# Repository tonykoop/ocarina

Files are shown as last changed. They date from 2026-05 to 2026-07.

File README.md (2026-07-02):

# Ocarina — Slip-Cast Ceramic Vessel-Flute Family

> *Engineering documentation for a 3D-printed-master, plaster-mold, cone-6-stoneware slip-cast ocarina family — from Helmholtz physics through the parametric design table to a V5 candidate build packet.*

**Status:** L2 V5 build-packet candidate

Current status: **V5 explorer/build-packet candidate, not build-ready**. The
repo has a parametric design table, OpenSCAD starter, SVG drawing previews, and
concept images, but the build-controlling values for chamber volume, voicing
geometry, clay shrinkage, and tuning still need physical measurement before
they can be treated as validated fabrication authority.

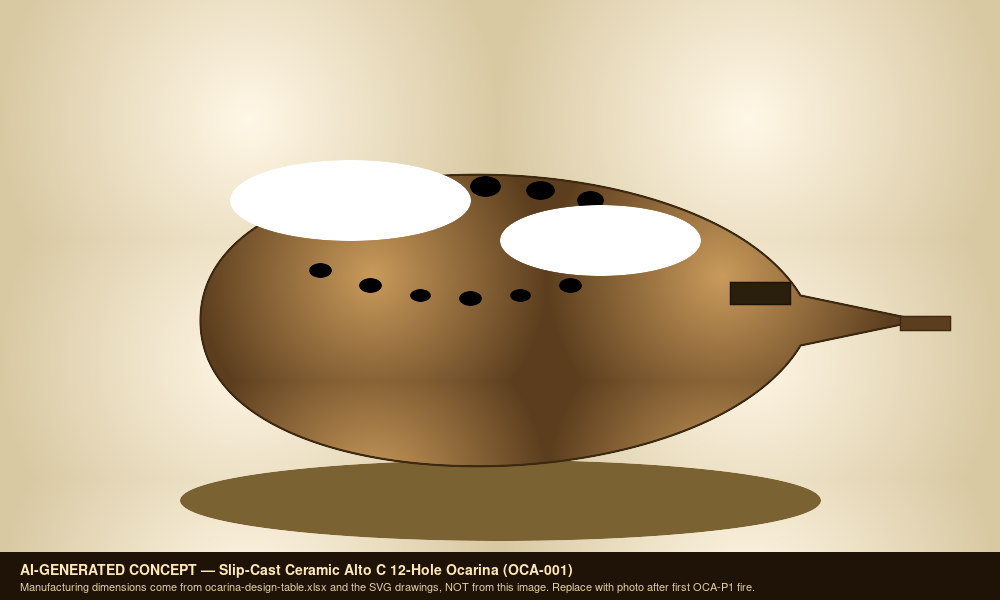
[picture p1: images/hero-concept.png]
Hero — AI-generated concept render of a slip-cast Alto C 12-hole ocarina (placeholder until first prototype is photographed)

*AI-generated concept render — replace with photo of first OCA-P1 prototype after firing. Manufacturing dimensions come from the parametric design table, not from this image.*

## What this is

Engineering documentation for a small family of slip-cast ceramic ocarinas, built around the Helmholtz vessel-resonator model and a 3D-printed-master / plaster-mold / Cone-6-stoneware production pipeline. The repository combines:

1. **A parametric design table** ([`ocarina-design-table.xlsx`](ocarina-design-table.xlsx)) — chamber volume, voicing-window geometry, wall thickness, shrinkage, and a 12-hole fingering chart with formula-driven hole-area / cumulative-area / frequency columns. Master scale factor `1/(1 - measured_shrinkage)` is parameterized; for a 12% shrinkage assumption, the master scales at ~1.136×.
2. **A full build packet** ([`design.md`](design.md), [`bom.csv`](bom.csv), [`sourcing.csv`](sourcing.csv), [`cut-list.csv`](cut-list.csv), [`validation.csv`](validation.csv), [`assembly-manual.md`](assembly-manual.md), [`supplier-rfq.md`](supplier-rfq.md), [`drawing-brief.md`](drawing-brief.md), [`visual-bom-brief.md`](visual-bom-brief.md), [`wolfram-starter.wl`](wolfram-starter.wl)) — the same scaffold used across the [`tonykoop`](https://github.com/tonykoop) musical-instrument catalogue.
3. **A capstone slide deck and printable shop packet** ([`capstone-deck.pptx`](capstone-deck.pptx), [`print-packet.pdf`](print-packet.pdf)) — recruiter-facing artifacts that show the design record, authority boundaries, and next validation gates.

Sister repos: [`gemshorn`](https://github.com/tonykoop/gemshorn) (where slip-cast horn-flute mold workflow was established and is the closest comparable build packet), [`transverse-flute`](https://github.com/tonykoop/transverse-flute) (slip-cast workflow at larger scale), [`flutes`](https://github.com/tonykoop/flutes) (the NAF / open-pipe family with empirical K2 bore corrections), and [`instrument-maker`](https://github.com/tonykoop/instrument-maker) (the agent skill that generated this packet).

## Background — what makes an ocarina different

The ocarina (Italian *little goose*) is a closed-cavity vessel flute. Unlike a transverse flute or a Native American style flute, **pitch is set by chamber volume and total open-hole area, not by tone-hole position along a bore**. The governing model is the Helmholtz resonator:

```
f = c/(2π) · √( A_open / (V_chamber · L_eff) )
```

where `A_open` is the cumulative open hole area, `V_chamber` is the closed cavity volume, and `L_eff = wall_thickness + 0.6·√(A_open/π)` is the effective neck length with a flanged-port end correction. The full physics treatment is in [`design.md`](design.md) (Governing Model section) and in [`wolfram-starter.wl`](wolfram-starter.wl).

The practical consequence is that ocarina hole positions are an **ergonomic** problem (where the fingers reach), not an acoustic one (where the standing wave wants the holes). This makes the ocarina an unusually clean parametric-design target — change the chamber volume, the whole register transposes; change the cumulative area, the fingering chart re-tunes — but it puts an unusually heavy burden on **fipple/voicing geometry**, which the Helmholtz model says nothing about and which has to be tuned empirically.

## V5 authority map

The current fabrication authority is limited to the design table and OpenSCAD
starter as **candidate geometry**, not validated production geometry:

- `ocarina-design-table.xlsx` carries the inferred workbook values for chamber
  volume, wall thickness, voicing-window size, shrinkage assumption, and hole
  schedule.
- `cad/ocarina_master.scad` is a parametric master-shape starter derived from
  those values. It does not validate the windway, labium, or final fired pitch.
- `family-spec.csv` records the vessel-flute scaling and authority status for
  chamber volume, voicing geometry, shrinkage, and tuning.
- `visual-output-register.csv` marks the CAD/design table as candidate
  fabrication authority and labels SVG/image outputs as previews or concepts.
- `cad/mcp-session-log.md` records that no MCP-generated V5 artifacts were
  created in this lane; future OpenSCAD/Blender/Illustrator/Photoshop sessions
  should append there.

## Family targets

The first prototype is the magazine-standard **Alto C 12-hole** (target low note A4 = 440 Hz, target high note F6 ≈ 1397 Hz, chamber volume 130 cm³ per the design table). The same parametric model can drive a Soprano C / Bass C extension once the Alto C voicing geometry is stable — see the prototype ladder in [`design.md`](design.md).

| Prototype | Goal | Success criteria |
|---|---|---|
| **OCA-P0** voicing tile | Fipple-only practice cavity | Clear tone on a disposable test cavity |
| **OCA-P1** closed vessel | Verify chamber volume + fipple | Stable A4-ish all-closed tone before holes |
| **OCA-P2** 4-hole | Prove tuning workflow | Four tuned notes within ±25 ¢ post-bisque |
| **OCA-P3** 12-hole | Full range | Chromatic A4–A5 playable, no blocked grip |
| **OCA-P4** matched set | Soprano / Alto / Bass C | Shared mold logic, shared glaze family |

## Hardware alignment — Bambu printer + ceramic kiln

This repo is one of the **slip-casting targets** for the in-flight Bambu printer + kiln pipeline. The build chain is:

1. Parametric design table sets fired-body dimensions.
2. Master scale factor `1/(1 - measured_shrinkage)` scales the master STL.
3. Bambu print masters in PLA (or sealable resin); sand layer lines and seal.
4. Two-piece plaster mother mold around the sealed master.
5. Slip-cast Cone 6 stoneware → demold leather-hard → cut voicing window and finger holes undersized → bisque → tune → glaze → final fire.
6. Validate against [`validation.csv`](validation.csv); fold corrections back into the design table.

The same pipeline serves the [`udu`](https://github.com/tonykoop/udu), [`gemshorn`](https://github.com/tonykoop/gemshorn), and [`transverse-flute`](https://github.com/tonykoop/transverse-flute) repos.

## Repository structure

```
ocarina/
├── README.md                       ← you are here
├── LICENSE                         ← CC-BY 4.0
│
├── design.md                       ← Helmholtz model, design intent, prototype ladder
├── ocarina-design-table.xlsx       ← parametric spreadsheet (formulas, blue inputs)
│
├── bom.csv                         ← bill of materials
├── sourcing.csv                    ← supplier/search tracker
├── cut-list.csv                    ← rough/finished dimensions, tolerances
├── validation.csv                  ← target/measured tuning + cents-error log
├── supplier-rfq.md                 ← RFQ template for slip / plaster / consumables
│
├── assembly-manual.md              ← shop-floor build sequence
├── drawing-brief.md                ← required views + critical dimensions for CAD
├── visual-bom-brief.md             ← visual-BOM art-direction brief
├── wolfram-starter.wl              ← Helmholtz physics starter notebook
│
├── capstone-deck.{md,pptx}         ← capstone slide deck (12 slides)
├── print-packet.{md,html,pdf}      ← combined print-ready shop packet (18 pp)
├── capstone-manifest.json          ← orientation manifest
│
├── cad/                            ← parametric body OpenSCAD starter
├── cnc/                            ← (deferred — slip-cast does not need CNC unless turning a wooden master)
├── drawings/                       ← SVG drawings: section, fipple detail, hole layout
├── images/                         ← AI-generated concept renders (placeholders)
└── evolution/                      ← Stage 0 evolution-pipeline intake (manifest, design-intent, revisions)
```

## Status

| Section | Status |
|---|---|
| Parametric design table + Helmholtz model | ✓ done |
| Build packet (BOM / sourcing / cut-list / validation / RFQ) | ✓ done |
| Assembly manual + drawing brief | ✓ done |
| Wolfram physics starter | ✓ done |
| Capstone deck + print packet | ✓ done (auto-generated, recruiter-facing) |
| Concept renders (AI-generated, captioned) | ✓ done (placeholders) |
| Parametric CAD (OpenSCAD starter) | candidate only (master-shape; voicing detail by hand) |
| Dimensioned drawings (SVG) | derived preview only until reviewed against CAD/design-table authority |
| V5 authority/register files | added: `family-spec.csv`, `visual-output-register.csv`, `validation-loop.csv`, `cad/mcp-session-log.md` |
| Production-ready CAD (.step / .stl) | **deferred** — generated after empirical voicing validation in build queue |
| Mold turning / CNC toolpaths | **deferred** — slip-cast workflow uses 3D-printed master, not turned wooden master |
| First OCA-P1 prototype build | forthcoming (Bambu + kiln pipeline) |

Tier 3 production files (.step, validated .stl, .dxf for laser, .gcode for CNC) are **out of scope until the first OCA-P1 prototype validates voicing geometry**. See the README's status table and [`design.md`](design.md) "Open Assumptions" for the deferral reasoning.

## License

Released under [CC-BY 4.0](LICENSE) — original written content, design files, photographs, and physics work in this repository are mine, free to reuse and adapt with credit.

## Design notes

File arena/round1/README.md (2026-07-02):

# Arena winner: ocarina (round1)

**Generated model** — the winning Code-CAD Arena candidate for this
instrument (entrant `antigravity-gemini-default`, blind-vote wins 1.5, objective pass-rate 0.833333).

This is an AI-generated arena artifact, NOT a measured master or a
validated build packet. See `provenance.json` for the full trial
record. Exported by `makerbench arena export-winners`.

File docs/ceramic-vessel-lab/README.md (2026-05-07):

# Ceramic Vessel Lab Addendum - Ocarina

This folder preserves the brainstorm/design packet that was developed in the shared `instrument-maker` workspace before the material was copied into the dedicated `ocarina` repo.

Use the repo-root files for the current production packet:

- `../../design.md`
- `../../ocarina-design-table.xlsx`
- `../../bom.csv`
- `../../sourcing.csv`
- `../../validation.csv`
- `../../assembly-manual.md`
- `../../print-packet.pdf`
- `../../capstone-deck.pptx`

Use this addendum for the earlier ceramic-vessel research framing:

- `design.md` - Alto C ocarina notes, Helmholtz model, mold strategy, and workbook cleanup flags.
- `assembly-manual.md` - CAD master through final tuning workflow.
- `bom.csv`, `sourcing.csv`, `validation.csv` - structured lab tables.
- `drawing-brief.md`, `visual-bom-brief.md` - documentation and image planning.
- `wolfram-starter.wl` - compact Helmholtz model starter.
- `Ocarina-brainstorm-design-table.xlsx` - copied source workbook from the shared brainstorm.
- `ceramic-vessel-instrument-lab.md` - cross-instrument ceramic vessel roadmap.

Nothing in this addendum overwrites the root-level v4 packet; it is here as provenance and research context.

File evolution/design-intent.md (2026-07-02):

# Design Intent — ocarina rev A

- Master CAD: `cad/ocarina_master.scad` (sha256: dbe5ac36bc03ff687ec57d1da0b3d720a6569ada6bf7fe08b9159e2718f1e306), driven by `ocarina-design-table.xlsx` (sha256: 442e99759ec02864dfd48abc05ec13afdeaa3071adc5c351f21350051b5849fa)
- Function: Closed-cavity ceramic vessel flute (Helmholtz resonator). Pitch is set by chamber volume and total open-hole area — NOT by tone-hole position along a bore. Hole positions are ergonomic, not acoustic. First target: magazine-standard Alto C 12-hole. f = c/(2π)·√(A_open/(V_chamber·L_eff)), L_eff = wall + 0.6·√(A_open/π).
- Environment: slip-cast Cone-6 stoneware via 3D-printed master + plaster mold; clay shrinkage (~12% assumed) scales the master at ~1.136×. Fipple/voicing geometry is empirical and outside the Helmholtz model.
- Target qty: 1 (prototype — OCA-P1 closed vessel first). Deadline: TBD. Budget/unit ceiling: TBD.

## Critical dimensions (carry tolerances)

| Feature | Nominal | Tolerance | Why critical | Source |
| --- | --- | --- | --- | --- |
| Chamber volume (Alto C / OCA-P1) | 130 cm³ | water-fill check at greenware/bisque/glaze | governs fundamental (A4 = 440 Hz) | family-spec.csv OCA-P1 (inferred_from_workbook) |
| Voicing window (OCA-P1) | 0.9 × 0.5 cm | empirical; do not finalize from table | tone speaking / voicing | family-spec.csv OCA-P1 (inferred_from_workbook) |
| Wall thickness (OCA-P1) | 0.4 cm | drying/leak/crack gate | shell strength + sealing | family-spec.csv OCA-P1 (inferred) |
| Master scale factor | 1/(1 − shrinkage) ≈ 1.136× @ 12% | recompute from measured clay test | fired size vs master | design table / family-spec (assumption_until_clay_test) |
| Target low note | A4 = 440 Hz | ±cents logged in validation.csv | tuning correctness | family-spec.csv OCA-P1 |
| Cumulative open-hole area (12-hole) | per design-table formula chart | tune undersized holes post-bisque | sets chromatic scale A4–F6 | ocarina-design-table.xlsx / family-spec OCA-P3 |

## Incidental (free for DFM)

- Vessel outer body styling, mouthpiece/duct exterior contour, glaze color/family, non-mating surface finish, sling/grip cosmetics.

## Must-nots (DFM may never violate)

- Windway/labium/fipple voicing geometry is tuning-sensitive: never freeze it from the table or a lossy mesh export — tune empirically and log (README / design.md; Helmholtz model says nothing about voicing).
- Do not expand to full 12-hole layout before OCA-P1 (chamber+fipple) and OCA-P2 (4-hole tuning) checks pass (family-spec next_measurement).
- Cut voicing window + finger holes undersized before bisque; tune up (README build chain).
- Do not treat production .step/.stl as authority until first prototype validates voicing geometry (README status).

## Material intent

- Preferred: Cone-6 stoneware slip; PLA (or sealable resin) 3D-printed master; two-piece plaster mother mold (per bom.csv / README build chain).
- Acceptable subs: per sourcing.csv / supplier-rfq.md (spec-first; live prices unverified; mouth-safe glazes only).
- Forbidden: non-mouth-safe interior finishes on played bodies.

## Stage status

Stage 0 intake complete 2026-07-01. Gate A (Alpha shop compile) NOT yet run — no concessions logged, nothing presented as shippable. Fabrication authority remains measurement-gated (V5 candidate, not build-ready).

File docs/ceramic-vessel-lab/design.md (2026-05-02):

# Ocarina Build Packet

## Source

- Design table: `docs/Ocarina.xlsx`
- Sheet: `Ocarina`
- Inspected range: `A1:H141`
- Workbook content observed: design inputs, size library, Helmholtz calculator, 12-hole fingering chart, ceramic workflow, BOM, design notes, and Wolfram notebook notes.

## Design Intent

Build a slip-cast ceramic Alto C 12-hole ocarina using a 3D-printed master and plaster mold workflow. The current table is focused on the standard "sweet potato" vessel-flute form, but the same model can be used as the baseline for sculptural vessel flutes.

## Governing Model

Ocarinas behave primarily as Helmholtz resonators:

```text
f = c/(2*pi) * sqrt(A_open/(V_chamber * L_eff))
```

Unlike a transverse flute or Native American style flute, pitch is driven by chamber volume and total open-hole area, not tone-hole distance along a bore. Hole position is still important for ergonomics, grip, and fingering logic.

## Current Workbook Inputs

| Field | Current value |
| --- | --- |
| Ocarina type | Alto C, 12-hole |
| Chamber volume | 130 cm3 |
| Wall thickness | 0.4 cm |
| Voicing window width | 0.9 cm |
| Voicing window height | 0.5 cm |
| Speed of sound | 34300 cm/s |
| Clay body | Cone 6 stoneware |
| Shrinkage | 12 percent |
| Target low note | A4, 440 Hz |
| Target high note | F6, 1397 Hz |

## Critical Design Features

- Chamber volume is the master tuning input. Measure it by water fill after CAD, master print, greenware, bisque, and glaze fire.
- Voicing window area sets the all-closed low-note behavior along with volume and effective neck length.
- Fipple geometry is the playability bottleneck: windway gap, labium angle, channel smoothness, and edge sharpness should be treated as first-class dimensions.
- Finger holes should start undersized. Enlarge to sharpen; flattening after over-enlarging is possible but slower and less clean.
- Exterior-only glazing is preferred for tuning stability and acoustic response. Mask the fipple, holes, and chamber interior.

## Workbook Improvement Notes

During inspection, rows 39-42 of the 12-hole fingering chart contain formulas for hole area, cumulative open area, and calculated frequency. Rows 43-51 currently show placeholder `=` cells instead of filled formulas. Recommended next workbook cleanup:

1. Copy the area formula pattern from `D40:D42` through `D51`.
2. Copy the cumulative area pattern from `E40:E42` through `E51`.
3. Copy the frequency formula pattern from `F40:F42` through `F51`.
4. Add measured frequency, cents error, and tuning action columns.
5. Add a note that hole combinations can be cross-fingered if total open area is equivalent.
6. Verify the size-library `Length (in)` column. Inspection showed serial-like values such as `46180`, so those cells may have been formatted or entered incorrectly.

## Mold Strategy

Use a 2-piece plaster mold for the main body. The first prototype can use a press-molded body to speed iteration, but production should move toward slip casting once the fipple and chamber volume are stable.

Recommended mold/CAD features:

- Split line around the widest body perimeter.
- Positive registration keys that do not trap clay.
- Pour/drain path or assembly opening appropriate to the chosen casting workflow.
- Removable or cleanable fipple detail. If the fipple is too delicate for the mold, cast a blank and hand-cut the voicing at leather-hard stage.
- Master scale factor: `1/(1 - shrinkage)`; for 12 percent shrinkage this is about `1.136`.

## Prototype Ladder

| Prototype | Goal | Success criteria |
| --- | --- | --- |
| OCA-P0 voicing tile | Practice windway/labium only | Clear tone on a disposable test cavity |
| OCA-P1 closed vessel | Verify chamber volume and fipple | Stable A4-ish all-closed tone before finger holes |
| OCA-P2 4-hole | Prove tuning workflow | Four tuned notes within +/-25 cents after bisque |
| OCA-P3 12-hole | Full range test | Chromatic pattern playable, no blocked grip |
| OCA-P4 matched set | Soprano C, Alto C, Bass C | Shared mold logic and glaze family |

## Open Assumptions

- Pricing in the workbook is an estimate and has not been date-checked.
- Clay shrinkage must be measured for Tony's actual slip, not assumed from supplier average.
- The fipple may need empirical iteration beyond the Helmholtz model.
- Exact ergonomics depend on hand span and final sculptural body shape.

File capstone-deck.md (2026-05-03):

# Slip-Cast Ceramic Ocarina (OCA-001) — v3.1 smoke test
- Musical instrument documentation capstone
- Build packet: ocarina
- Generated: 2026-05-02

---

# Project Intent
- Build a slip-cast ceramic Alto C 12-hole ocarina using a 3D-printed master and plaster mold workflow. The current table is focused on the standard "sweet potato" vessel-flute form, but the same model can be used as the baseline for sculptural vessel flutes.

_Speaker notes:_ Read design.md before committing to dimensions or sourcing decisions.

---

# Physics Model
- Ocarinas behave primarily as Helmholtz resonators:

```
f = c/(2*pi) * sqrt(A_open/(V_chamber * L_eff))
```

_Speaker notes:_ Governing equations extracted verbatim from design.md. Apply empirical corrections (NAF K2, scale offsets) only where the model permits — see references/acoustic-models.md.

---

# How To Use This Packet
- Start with design.md for intent and assumptions.
- Use bom.csv, sourcing.csv, and cut-list.csv before buying or cutting.
- Use drawing-brief.md and CAD/CNC folders before machining.
- Print the packet for shopping, shop work, and validation.

---

# File Map
- design.md: Project intent, catalog metadata, assumptions, and validation plan.
- bom.csv: Starter bill of materials with part categories, quantities, drawing refs, and notes.
- sourcing.csv: Supplier/search tracker with specs, price/date fields, lead time, substitutes, and risks.
- cut-list.csv: Rough/final stock sizes, material, grain/orientation, operations, yield, and offcuts.
- drawing-brief.md: Manufacturing drawing and technical product sketch brief.
- assembly-manual.md: Shop-facing sequence, tools, fixtures, safety, tuning, finishing, and maintenance notes.
- validation.csv: Target/measured values, tolerance, environment, result, and tuning/build action log.
- supplier-rfq.md: Supplier email/request-for-quote starter.

---

# Build Workflow
- Design and assumptions
- Source materials and hardware
- Prepare stock, fixtures, and CNC/laser/lathe setup
- Assemble, tune, finish, and validate

---

# Sourcing And BOM
- BOM gives part categories and drawing references.
- Sourcing tracks search terms, supplier candidates, price/date, lead time, substitutions.
- Visual BOM brief turns the parts list into a presentation-ready image board.

---

# Shop Packet
- Cut list for lumber/sheet/blank planning.
- Assembly manual for away-from-keyboard work.
- Validation sheet for measured dimensions, tuning, pass/fail checks.

---

# Drawings, CAD, CNC
- drawing-brief.md defines required views, dimensions, datums, sketch intent.
- cad/ holds models and design tables.
- cnc/ holds CAM, toolpaths, setup sheets, dry-run notes.
- drawings/ holds PDFs, SVGs, DXFs, drawing exports.





---

# Images And Screenshots
- images\exploded-view-concept.png
- images\exploded-view-concept.svg
- images\hero-concept.png
- images\hero-concept.svg
- images\mold-cross-section-concept.png
- images\mold-cross-section-concept.svg

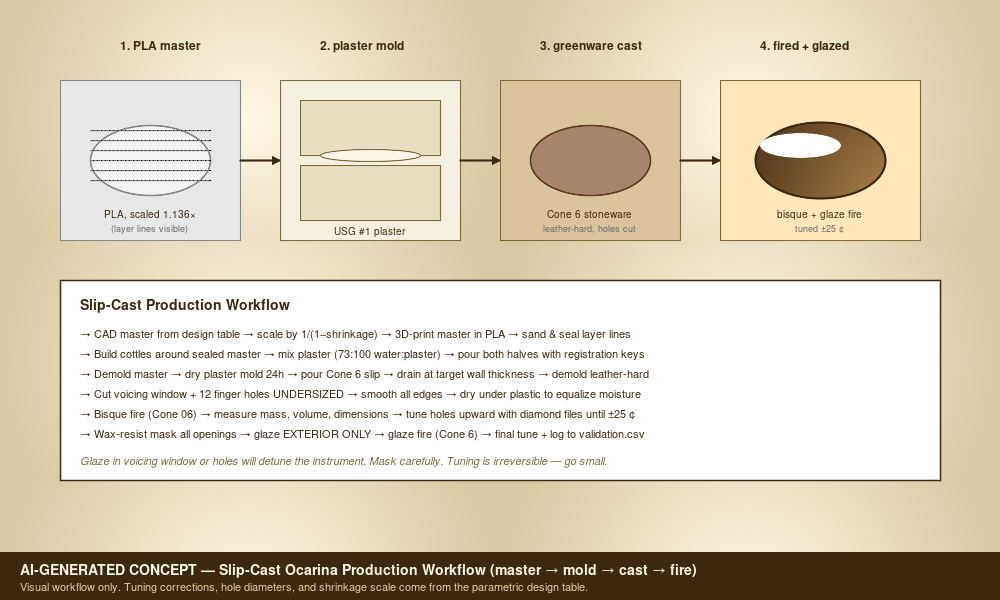
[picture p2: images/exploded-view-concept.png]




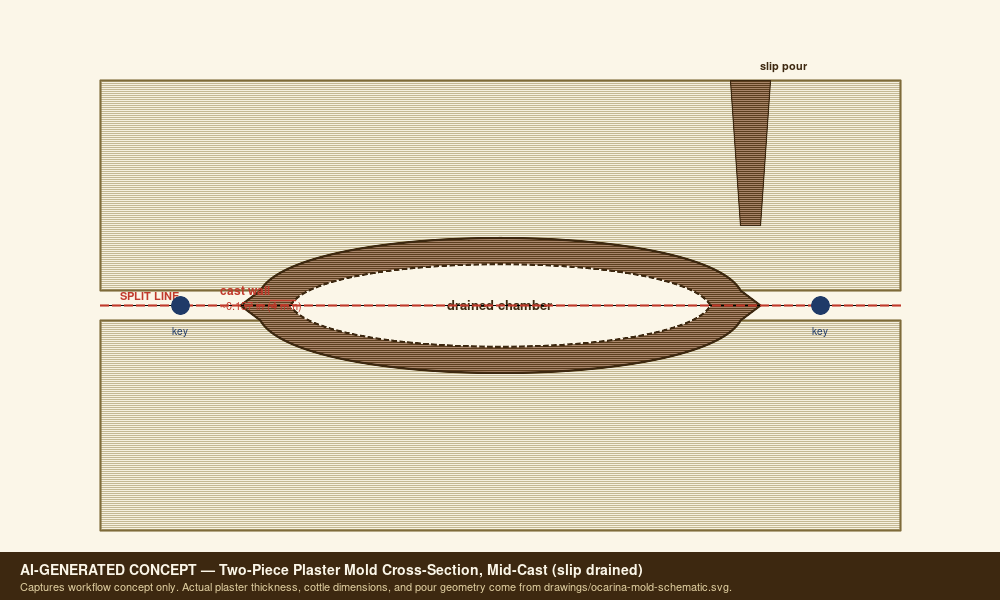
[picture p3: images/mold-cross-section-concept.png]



---

# Validation Plan
- A4 = 440 Hz reference check.
- Tuning targets logged in validation.csv.
- Critical dimensions verified against design sheet and CAD.
- Photos and revision notes after each major step.

---

# Open Risks / Decisions
- TBDs in design sheet and BOM.
- Supplier price/availability not yet verified.
- Generated images marked as concept placeholders.
- Empirical corrections await measured prototype data.

---

# Next Actions
- Replace TBDs with measured/source-backed values.
- Verify live supplier price and availability before buying.
- Export final drawings and visual BOM images.
- Regenerate this deck and print packet after final edits.

---

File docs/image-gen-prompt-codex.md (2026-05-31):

# Image Generation Prompt

Concept visualization only. Do not treat generated images as dimensional, tuning, CAD, STL, mold, or fabrication authority.

## Hero Prompt

Photorealistic studio product photograph of a finished slip-cast ceramic Alto C twelve-hole ocarina concept, sweet-potato vessel shape with satin Cone 6 stoneware finish, integrated fipple mouthpiece, voicing window, ergonomic tone-hole layout, and smooth exterior-only glaze. Arrange with a plaster mold half and a small water-fill beaker as scale cues, clean studio background, soft directional studio lighting, three-quarter product angle, about a 50mm lens, high detail.

## In-Context Prompt

Photorealistic ceramic studio scene showing the ocarina concept beside a sealed 3D-printed master, plaster mold, greenware body, calipers, tuning tools, and a tuner. Natural light, clay dust, practical slip-casting workflow, environmental storytelling about chamber volume, voicing tests, shrinkage, and post-bisque tuning.

## Detail/Macro Prompt

Macro close-up of the ocarina fipple and voicing window: smooth ceramic windway exit, sharp labium edge, satin glaze stopped away from the acoustic edge, tiny clay texture, nearby tone holes softly blurred, photorealistic high detail.

## Negative / Avoid

Avoid logos, watermarks, readable text, flute pipe geometry, impossible holes through the chamber, fake maker marks, wet glaze inside the windway, distorted hands, and dimension callouts.

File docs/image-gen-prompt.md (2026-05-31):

# Image-Gen Prompts

Concept image only; not fabrication authority. Do not include cut-ready dimensions, hole locations, or toolpaths.

## Hero Prompt

A single finished slip-cast ceramic Alto C ocarina — the classic rounded "sweet potato" vessel-flute silhouette, a smooth closed cavity that swells in the middle and tapers to a short stub mouthpiece at one end. The recognizable features that read it as an ocarina: a small fipple mouthpiece with a flat blown end, a rectangular voicing window with a clean sharp labium edge cut into the upper body just past the mouthpiece, and a scatter of round finger holes of varying sizes across the rounded belly with no bore tube running through it. The body is Cone 6 stoneware with an exterior-only satin glaze that leaves the voicing window, finger-hole rims, and mouth interior as bare matte clay; the surface shows the soft hand-finished roundness of a cast-and-tuned ceramic object. Scale cues read as a palm-sized hand instrument. Clean neutral light-grey studio background, soft directional studio light grazing across the glazed curve to show form, 3/4 product-photography angle, ~50mm lens, high detail, photorealistic, no text labels.

## In-Context Prompt

The slip-cast ceramic ocarina resting on a maker's bench in a small ceramics workshop, staged among the workflow that produced it — a sealed PLA 3D-printed master, a two-piece plaster mother mold, and a leather-hard greenware blank set nearby, suggesting the digital-master to fired-vessel pipeline. Warm natural window light, a kiln and tuner just out of focus in the background, shallow depth of field keeping the finished glazed ocarina sharp. Concept visualization only, environmental storytelling about a ceramic vessel-flute being tuned by hand.

## Detail Prompt

Macro close-up of the fipple voicing mechanism: the flat blown mouthpiece end, the narrow windway channel, and the rectangular voicing window where the air sheet strikes a crisp sharp labium edge cut into the stoneware body. Raking low-angle light emphasizes the sharpness of the labium edge, the smoothness of the windway, and the contrast between the satin exterior glaze and the bare matte clay left unglazed inside the window and around the hole rims. High detail, no measurements.

## Negative / Avoid

No text, logos, watermarks, or fake maker marks; no dimension callouts or measurement lines; no impossible mechanisms; no straight bore tube or transverse-flute body (this is a closed Helmholtz vessel, not a pipe); anatomically plausible hands if a player is shown.

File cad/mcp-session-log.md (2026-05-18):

# MCP Session Log

This log tracks V5 visual/CAD provenance for `tonykoop/ocarina`.

| artifact | tool | timestamp_utc | session_id | parent_artifact | authority | notes |
| --- | --- | --- | --- | --- | --- | --- |
| family-spec.csv | Codex local edit | 2026-05-18 | round30-v5-explorer-1 | design.md; validation.csv; ocarina-design-table.xlsx | planning ledger | Records vessel-flute authority status without claiming measured Helmholtz validation. |
| visual-output-register.csv | Codex local edit | 2026-05-18 | round30-v5-explorer-1 | cad/ocarina_master.scad; ocarina-design-table.xlsx; drawings/*.svg; images/*.png | authority register | Marks design table and OpenSCAD as candidate fabrication authority; marks SVG/images as preview/concept only. |
| validation-loop.csv | Codex local edit | 2026-05-18 | round30-v5-explorer-1 | validation.csv; drawing-brief.md; cut-list.csv | measurement plan | Adds empirical close-the-loop checks for chamber volume, shrinkage, voicing, and visual authority. |

No OpenSCAD MCP, Blender MCP, Illustrator MCP, Photoshop MCP, or image-generation
session was run in this lane. Future generated V5 artifacts should append one
row per tool session and should name their parent artifact before any output is
treated as fabrication or presentation authority.

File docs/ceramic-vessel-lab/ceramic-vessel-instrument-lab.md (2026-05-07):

# Ceramic Vessel Instrument Lab

This folder turns the existing `Ocarina.xlsx` and `Udu.xlsx` design tables into shop-facing build packets, then extends the same Helmholtz-resonator logic into a new vessel-flute research track.

## Source Files

| Instrument | Live design table | Build packet |
| --- | --- | --- |
| Ocarina | `docs/Ocarina.xlsx` | `docs/build-packets/ocarina/` |
| Udu drum family | `docs/Udu.xlsx` | `docs/build-packets/udu-drum-family/` |
| Experimental vessel flutes | TBD design table | `docs/build-packets/vessel-flute-lab/` |

## Program Goal

Use slip casting and 3D-printed mold masters to create repeatable ceramic vessel instruments whose pitch, response, and timbre can be tuned through measured cavity volume, wall thickness, voicing geometry, hole area, and firing shrinkage.

This is a good first ceramic instrument program because the udu, ocarina, water whistle, and sculptural vessel flute all share the same governing model:

```text
f = c/(2*pi) * sqrt(A_open/(V_chamber * L_eff))
```

The interesting part is not just hitting a note. It is learning how fired ceramic moves the model:

- Clay shrinkage changes volume, openings, and wall thickness.
- Wall thickness affects shell tap tone, projection, weight, and drying risk.
- Glaze changes mass, edge sharpness, and hole size.
- Mold drainage time controls cast wall thickness.
- Fipple and labium geometry often dominate playability more than the chamber formula.

## Recommended Build Order

1. **Small udu** - Fastest validation of slip-cast chamber volume, wall thickness, and two-port Helmholtz behavior.
2. **Alto C ocarina test body** - Adds fipple voicing and multi-hole tuning without requiring long straight bores.
3. **Water whistle / bird vessel** - Same physics with water-variable volume and sculptural freedom.
4. **Experimental vessel flute series** - Organic forms, multiple chambers, drone vents, and unusual hand layouts.
5. **Ceramic body electric violin** - Move here after mold repeatability, structural inserts, and firing distortion are under control.

## Shared Measurement Protocol

Every prototype should get a build number and the same measurements:

| Stage | Measurements |
| --- | --- |
| CAD master | Target chamber volume, target opening diameters, wall target, scale factor for shrinkage |
| Printed master | Measured master dimensions, print material, sealant, surface finish |
| Plaster mold | Mold weight, dry time, number of pours, registration quality |
| Green cast | Pour time, drain time, wall thickness sample, leather-hard mass, hole diameters |
| Bone dry | Mass, visible cracks/warps, chamber volume if measurable |
| Bisque | Mass, dimensions, volume, open-hole frequencies, fipple response |
| Glaze fired | Final mass, dimensions, volume, frequencies, cents error, tuning changes |

## Key Research Questions

- How close does the Helmholtz model predict greenware, bisque, and glaze-fired frequencies?
- Does stoneware or porcelain give better voicing stability for small fipple instruments?
- How much does exterior-only glaze shift ocarina/vessel-flute pitch?
- What wall thickness gives the best balance between durability and lively ceramic tap tone?
- Can 3D printed masters create vessel shapes that are hard to hand-build but still mold-release cleanly?
- Can non-round, organic chambers be reduced to measured water volume for reliable tuning?
- Can a vessel flute combine a Native American style breath feel with ocarina-style pitch control?

## Documentation To Keep Together

Each build packet uses this structure:

- `design.md` - source table, model, design intent, assumptions, and next improvements.
- `bom.csv` - material and tool list with workbook estimates where available.
- `sourcing.csv` - supplier/search-term fields without claiming current availability.
- `validation.csv` - tuning, shrinkage, wall-thickness, and build-result log.
- `assembly-manual.md` - shop workflow from CAD master through final tuning.
- `drawing-brief.md` - what the manufacturable drawing or CAD package must show.
- `visual-bom-brief.md` - image/BOM plate direction for future documentation.
- `wolfram-starter.wl` - notebook starter for physics exploration.

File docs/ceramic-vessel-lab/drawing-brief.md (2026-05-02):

# Ocarina Drawing Brief

## Required Views

- Top view with body outline, hole layout, hand assignment, and centerline.
- Side view with mouthpiece axis, windway height, labium angle, body thickness, and split line.
- Section through fipple showing windway, labium, window, and chamber connection.
- Section through body showing chamber volume reference, target wall thickness, and mold split.
- Detail view for hole diameters and post-fire tuning allowance.
- Mold view showing plaster parting line, registration keys, pour/drain plan, and cottle clearance.

## Critical Dimensions

| Dimension | Source | Tolerance intent |
| --- | --- | --- |
| Chamber volume | Workbook input and water-fill measurement | Tuning critical |
| Voicing window width/height | Workbook input | Playability critical |
| Windway gap | CAD/test-piece measurement | Playability critical |
| Labium angle and edge thickness | CAD/test-piece measurement | Playability critical |
| Wall thickness | Workbook input and cast measurement | Tone/drying critical |
| Hole diameters | Workbook chart and tuning log | Tuning critical |
| Master scale factor | Measured clay shrinkage | Process critical |

## Notes For CAD

- Store chamber volume as a named parameter.
- Store shrinkage factor as a named parameter.
- Separate final fired dimensions from master dimensions.
- Mark fipple geometry as prototype-sensitive; do not freeze it until test pieces speak reliably.
- Include a versioned body ID so castings can be tied back to the CAD master.

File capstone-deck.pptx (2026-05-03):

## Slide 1

Slip-Cast Ceramic Ocarina (OCA-001) — v3.1 smoke test

Musical instrument documentation capstone
Build packet: ocarina
Generated: 2026-05-02

Slip-Cast Ceramic Ocarina (OCA-001) — v3.1 smoke test | Slide 1 of 13

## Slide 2

Project Intent

• Build a slip-cast ceramic Alto C 12-hole ocarina using a 3D-printed master and plaster mold workflow. The current table is focused on the standard "sweet potato" vessel-flute form, but the same model can be used as the baseline for sculptural vessel flutes.

Slip-Cast Ceramic Ocarina (OCA-001) — v3.1 smoke test | Slide 2 of 13

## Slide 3

Physics Model

• Ocarinas behave primarily as Helmholtz resonators:
f = c/(2*pi) * sqrt(A_open/(V_chamber * L_eff))

Slip-Cast Ceramic Ocarina (OCA-001) — v3.1 smoke test | Slide 3 of 13

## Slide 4

How To Use This Packet

• Start with design.md for intent and assumptions.
• Use bom.csv, sourcing.csv, and cut-list.csv before buying or cutting.
• Use drawing-brief.md and CAD/CNC folders before machining.
• Print the packet for shopping, shop work, and validation.

Slip-Cast Ceramic Ocarina (OCA-001) — v3.1 smoke test | Slide 4 of 13

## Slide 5

File Map

• design.md: Project intent, catalog metadata, assumptions, and validation plan.
• bom.csv: Starter bill of materials with part categories, quantities, drawing refs, and notes.
• sourcing.csv: Supplier/search tracker with specs, price/date fields, lead time, substitutes, and risks.
• cut-list.csv: Rough/final stock sizes, material, grain/orientation, operations, yield, and offcuts.
• drawing-brief.md: Manufacturing drawing and technical product sketch brief.
• assembly-manual.md: Shop-facing sequence, tools, fixtures, safety, tuning, finishing, and maintenance notes.
• validation.csv: Target/measured values, tolerance, environment, result, and tuning/build action log.
• supplier-rfq.md: Supplier email/request-for-quote starter.

Slip-Cast Ceramic Ocarina (OCA-001) — v3.1 smoke test | Slide 5 of 13

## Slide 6

Build Workflow

• Design and assumptions
• Source materials and hardware
• Prepare stock, fixtures, and CNC/laser/lathe setup
• Assemble, tune, finish, and validate

Slip-Cast Ceramic Ocarina (OCA-001) — v3.1 smoke test | Slide 6 of 13

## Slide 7

Sourcing And BOM

• BOM gives part categories and drawing references.
• Sourcing tracks search terms, supplier candidates, price/date, lead time, substitutions.
• Visual BOM brief turns the parts list into a presentation-ready image board.

Slip-Cast Ceramic Ocarina (OCA-001) — v3.1 smoke test | Slide 7 of 13

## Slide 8

Shop Packet

• Cut list for lumber/sheet/blank planning.
• Assembly manual for away-from-keyboard work.
• Validation sheet for measured dimensions, tuning, pass/fail checks.

Slip-Cast Ceramic Ocarina (OCA-001) — v3.1 smoke test | Slide 8 of 13

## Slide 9

Drawings, CAD, CNC

• drawing-brief.md defines required views, dimensions, datums, sketch intent.
• cad/ holds models and design tables.
• cnc/ holds CAM, toolpaths, setup sheets, dry-run notes.
• drawings/ holds PDFs, SVGs, DXFs, drawing exports.

Slip-Cast Ceramic Ocarina (OCA-001) — v3.1 smoke test | Slide 9 of 13

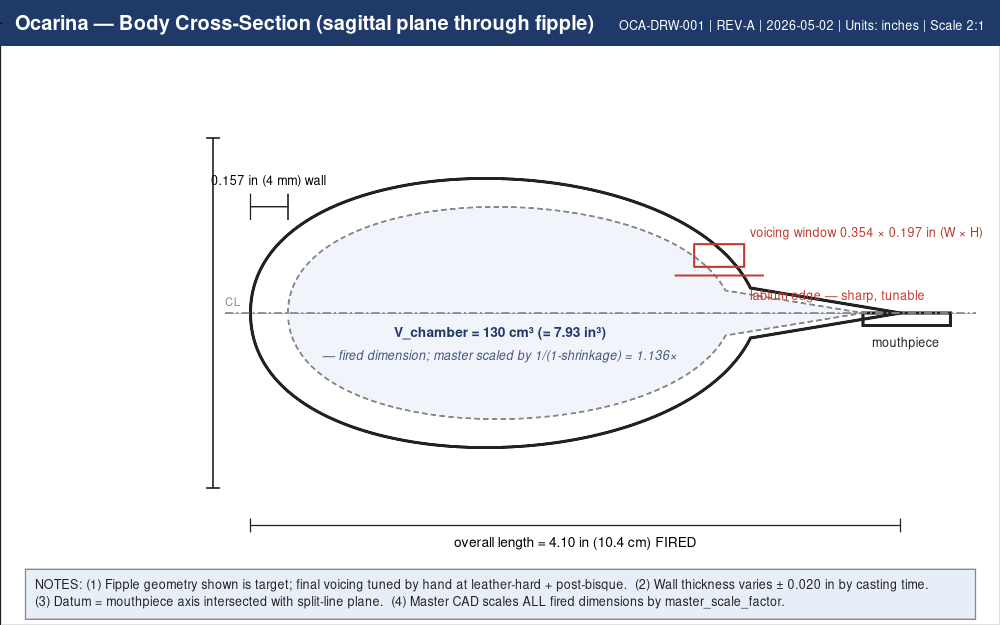
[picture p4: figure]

ocarina-body-section.png

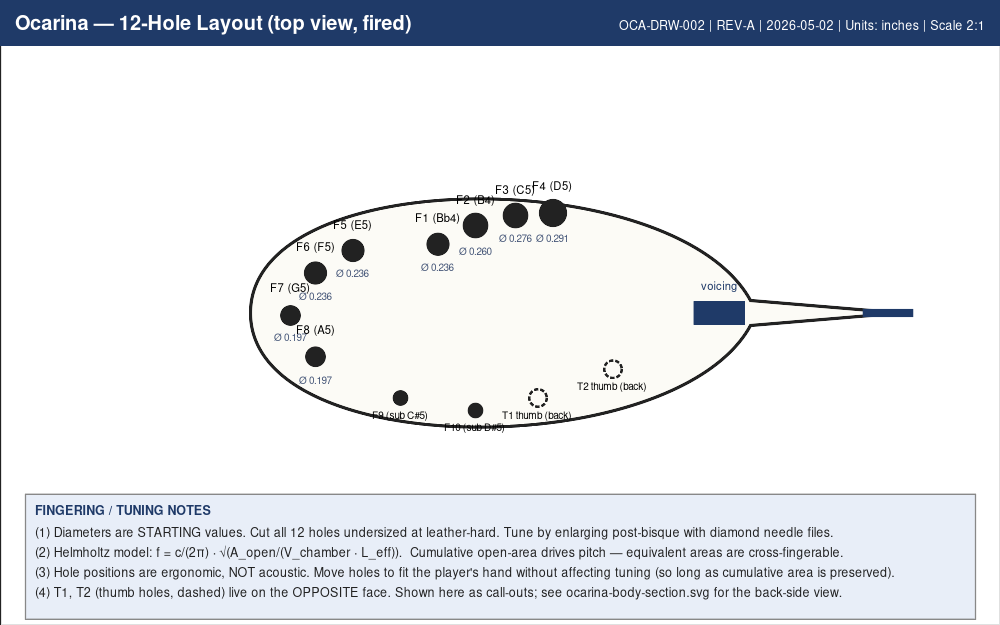
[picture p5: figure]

ocarina-hole-layout.png

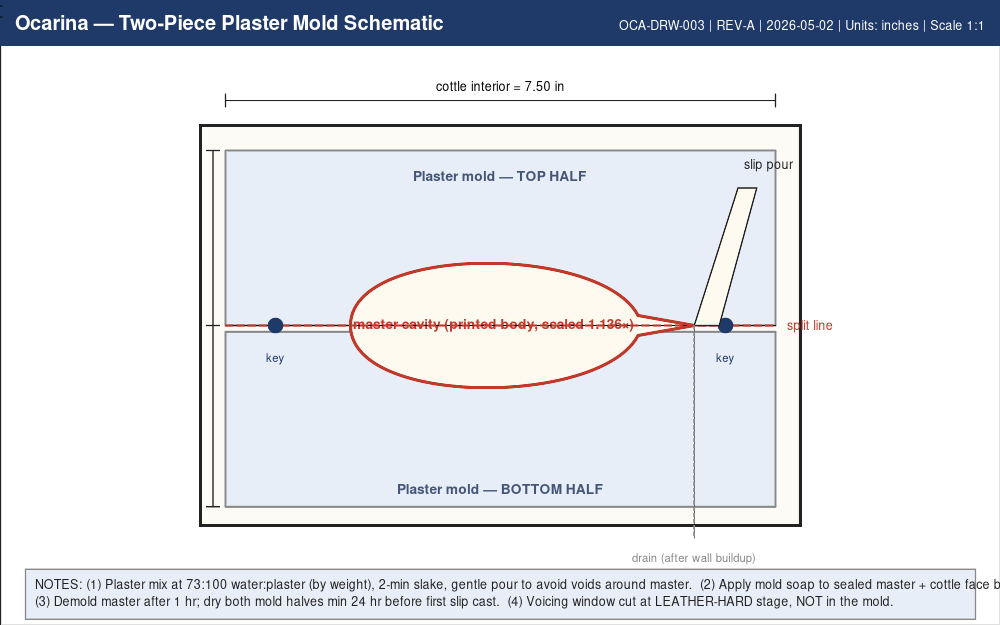
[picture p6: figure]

ocarina-mold-schematic.png

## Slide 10

Images And Screenshots

• images\exploded-view-concept.png
• images\exploded-view-concept.svg
• images\hero-concept.png
• images\hero-concept.svg
• images\mold-cross-section-concept.png
• images\mold-cross-section-concept.svg

Slip-Cast Ceramic Ocarina (OCA-001) — v3.1 smoke test | Slide 10 of 13


exploded-view-concept.png


hero-concept.png


mold-cross-section-concept.png

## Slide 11

Validation Plan

• A4 = 440 Hz reference check.
• Tuning targets logged in validation.csv.
• Critical dimensions verified against design sheet and CAD.
• Photos and revision notes after each major step.

Slip-Cast Ceramic Ocarina (OCA-001) — v3.1 smoke test | Slide 11 of 13

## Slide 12

Open Risks / Decisions

• TBDs in design sheet and BOM.
• Supplier price/availability not yet verified.
• Generated images marked as concept placeholders.
• Empirical corrections await measured prototype data.

Slip-Cast Ceramic Ocarina (OCA-001) — v3.1 smoke test | Slide 12 of 13

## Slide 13

Next Actions

• Replace TBDs with measured/source-backed values.
• Verify live supplier price and availability before buying.
• Export final drawings and visual BOM images.
• Regenerate this deck and print packet after final edits.

Slip-Cast Ceramic Ocarina (OCA-001) — v3.1 smoke test | Slide 13 of 13

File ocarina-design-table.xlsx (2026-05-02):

Ocarina — Helmholtz Vessel Flute + Ceramic Slip Casting Workflow
12-Hole Transverse · Helmholtz Resonator: f = (c/2π)√(S/(V×L_eff)) · Pitch = f(open hole area / chamber volume) · 3D Print → Plaster Mold → Slip Cast
DESIGN INPUTS
Ocarina Type | Alto C (12-hole) | ← Most popular; good range, comfortable size
Chamber Volume (cm³) | 130 | ← Measured by water fill; 130 cm³ typical for Alto C
Wall Thickness (cm) | 0.4 | ← 3-5 mm; thinner = brighter; thicker = warmer
Voicing Window W (cm) | 0.90 | ← Width of the fipple windway opening
Voicing Window H (cm) | 0.50 | ← Height of the fipple windway opening
Voicing Area (cm²) |  | ← = W × H (formula)
Speed of Sound (cm/s) | 34300 | ← 343 m/s at 20°C; warm breath ≈ 35000
Number of Finger Holes | 12
Clay Body | Stoneware (Cone 6) | ← Stoneware, porcelain, or earthenware
Shrinkage Rate (%) | 12 | ← 10-15% typical; measure YOUR clay body
Target Low Note | A4 (440 Hz)
Target High Note | F6 (1397 Hz)
OCARINA SIZE LIBRARY
Type | Vol (cm³) | Range | Length (in) | Holes | Best For
Soprano G | 50 | G5-E7 | 2026-03-04 | 12 | Bright, piccolo-like; tiny
Soprano F | 65 | F5-D7 | 2026-04-05 | 12 | High, sweet tone
Soprano C | 80 | C5-A6 | 2026-05-06 | 12 | Good starter size
Alto C ⭐ | 130 | A4-F6 | 2026-06-07 | 12 | MOST POPULAR; rich tone; art fair best seller
Alto G | 200 | G4-E6 | 2026-07-08 | 12 | Warm, mellow; orchestra sub-bass
Alto F | 250 | F4-D6 | 2026-08-09 | 12 | Deep, breathy; large hands needed
Bass C | 500 | C4-A5 | 2026-10-12 | 12 | Very deep; requires strong breath; impressive
HELMHOLTZ CALCULATOR — Lowest Note (All Holes Closed)
Voicing Area S (cm²)
End Correction (cm)
Effective Neck Length L_eff (cm)
Helmholtz Frequency (Hz) |  | ← Adjust voicing area and volume to hit target low note
Nearest Note
Cents from Target A4 |  | cents (0 = perfect A4; negative = flat)
12-HOLE FINGERING CHART — Hole Sizes & Calculated Frequencies
← Hole diameters (column C) are BLUE INPUTS. Adjust to tune each note. Open holes cumulatively from bottom.
# | Note | Hole Ø (mm) | Hole Area (cm²) | Cum. Open Area | Calc Freq (Hz) | Target Freq | Hand
0 | A4 (all closed) | — | — |  |  | 440.0 | —
1 | Bb4 | 5.0 |  |  |  | 466.2 | R pinky
2 | B4 | 5.5 |  |  |  | 493.9 | R ring
3 | C5 | 6.0 |  |  |  | 523.3 | R middle
4 | C#5 | 6.0 |  |  |  | 554.4 | R index
5 | D5 | 6.5 |  |  |  | 587.3 | L pinky
6 | D#5 | 6.5 |  |  |  | 622.3 | L ring
7 | E5 | 7.0 |  |  |  | 659.3 | L middle
8 | F5 | 7.0 |  |  |  | 698.5 | L index
9 | F#5 | 7.5 |  |  |  | 740.0 | R sub-hole
10 | G5 | 8.0 |  |  |  | 784.0 | L sub-hole
11 | G#5 | 8.5 |  |  |  | 830.6 | R thumb
12 | A5+ | 9.0 |  |  |  | 880.0 | L thumb
CERAMIC WORKFLOW — 3D Print → Plaster Mold → Slip Cast
# | Phase | Operation | Tools / Materials | Key Notes
1 | CAD | Model ocarina body in SolidWorks as 2-piece split (top + bottom halves) | SolidWorks / Fusion 360 | Scale UP by shrinkage factor (e.g. 112% for 12% shrinkage). Include fipple channel in top half.
2 | 3D Print | Print positive master (both halves) on FDM or resin printer | FDM printer + PLA, or resin SLA | Sand smooth to remove layer lines. Seal with lacquer or shellac.
3 | Mold Making | Embed 3D print in plaster to create 2-part press mold (one for each half) | Pottery plaster (#1), mold soap, cottle boards | Plaster thickness 1.5-2 in around print. Dry 3+ days before use.
4 | Press Mold | Press clay slabs into each mold half. Score edges, apply slip, join halves. | Stoneware clay, slip, scoring tool | Consistent wall thickness = consistent pitch. Target 4mm walls.
5 | Fipple | Carve windway and labium (sound edge) into the mouthpiece area | Needle tool, loop tool | THE critical step. 45° labium angle. Windway 1-2mm gap. Test blow before drying.
6 | Holes | Punch finger holes using graduated drill bits or clay cutters | Drill bits, hole punches, tuner | Start SMALL — you can always enlarge. Use hole Ø from chart above. Tune wet.
7 | Dry | Slow-dry in plastic bag for 3-7 days to prevent cracking | Plastic bag, damp towel | Even drying is critical — thin areas dry faster and crack.
8 | Bisque Fire | Fire to Cone 06 (1828°F / 998°C) to harden clay body | Kiln | Clay shrinks to final size here. Pitch may shift — re-tune holes after.
9 | Tune | Fine-tune each hole with diamond file or Dremel. Check with chromatic tuner. | Diamond needle files, Dremel, tuner | Enlarge holes to raise pitch (sharpen). Can add clay slip to shrink (flatten).
10 | Glaze | Apply glaze to exterior only. Keep interior, holes, and fipple unglazed. | Glaze, brush, wax resist | Wax resist on holes + fipple BEFORE glazing. Glaze changes hole size slightly.
11 | Glaze Fire | Fire to Cone 6 (2232°F / 1222°C) for stoneware; Cone 10 for porcelain | Kiln | Final shrinkage here. Re-check tuning after — may need very fine adjustment.
12 | Final Tune | Last tuning pass with diamond files if needed | Diamond files, tuner | The fired ceramic is much harder to file — go slowly. Most ocarinas need this.
BILL OF MATERIALS
# | Item | Qty | Spec | Notes | Est. Cost
1 | 3D print filament (master) | ~50g | PLA or resin | 2-piece split master; sand and seal | $2-5
2 | Pottery plaster (#1) | 10 lbs | USG #1 Pottery Plaster | Makes 2-3 mold sets; each set lasts 50-100 casts | $15-25
3 | Stoneware slip or clay body | 25 lbs | Cone 6 stoneware | ~0.5 lb per ocarina; 25 lbs = 50+ ocarinas | $20-35
4 | Glazes (assorted) | 3-5 pints | Cone 6 food-safe glazes | Exterior decoration; multiple colors for variety | $30-60
5 | Diamond needle files | 1 set | Assorted shapes | For post-fire hole tuning | $10-20
6 | Chromatic tuner | 1 | Clip-on or app | Essential for hole tuning; need cent accuracy | $15-30
7 | Mold soap / release | 1 | Murphy's oil soap or mold soap | Apply to 3D print before plaster pour | $5-10
8 | Kiln firing (outsource) | Per load | Bisque + glaze fire | Community kiln at Maker Nexus or ceramics studio | $20-50/load
 | ESTIMATED TOTAL (startup) |  |  |  | $117-235
 | Cost per ocarina (after startup) | ← Sell at $25-60 each at art fairs |  |  | $3-8
DESIGN NOTES
1. PITCH = OPEN AREA / VOLUME. Unlike flutes, hole LOCATION doesn't matter — only total open area. This is the Helmholtz advantage.
2. Clay shrinkage changes volume AND hole sizes. Scale the 3D master UP by your shrinkage rate. Expect 2-3 iterations before good tuning.
3. The fipple (windway + labium) is the hardest part. Practice on test pieces before committing to a glazed ocarina.
4. Start holes SMALL and enlarge to tune. Easier to remove clay than add it. Diamond files after firing are your friend.
5. Each mold set produces 50-100 ocarinas before wearing out. At $3-8 per piece and $25-60 selling price, the margins are excellent.
6. ALTERNATIVE: Skip the mold entirely and hand-build (pinch pot method). Faster for prototyping, slower for production.
7. Porcelain produces a brighter, more projecting tone than stoneware. But porcelain is harder to work with (more warping, higher shrinkage).
8. The transparent glaze on exterior + unglazed interior is traditional. Some makers leave the whole exterior unglazed for a more earthy tone.
9. ART FAIR PRICING: Alto C ocarina in glazed stoneware with custom artwork → $35-60. Soprano C (smaller, easier) → $25-40.
10. SERIES CONCEPT: Offer 3 sizes (Soprano C, Alto C, Bass C) as a matched set with consistent glaze pattern. Premium gift box: $100-150.
WOLFRAM CLOUD NOTEBOOK SPEC — OCARINA
Helmholtz vessel flute — pitch from cavity volume + hole area, NOT pipe length.
§1 — Origin & Etymology
Origin: ancient Mesoamerican (Maya, Aztec) clay vessel flutes; 5000+ years old. Modern European form codified 1853 by Giuseppe Donati (Budrio, Italy) — the 'sweet potato' shape.
Ocarina' from Italian 'ocarina' (small goose). Donati's 7-piece family standardized; Asian variants (xun in China, hun in Korea) parallel ancient pottery flutes.
Wolfram items: GeoGraphics Mesoamerica + Italy + East Asia; TimelinePlot[{−3000 Mesoamerica, ancient xun, 1853 Donati, 1998 Zelda Ocarina of Time, present}].
§2 — Physics
Helmholtz resonator: f = (c/2π)·√(A_open/(V·L_neck)). NOT a pipe — pitch depends on TOTAL open hole area, not which holes are open.
Implication: any combination of holes giving same total area gives same pitch. Fingering systems exploit this for ergonomic note layouts.
Wolfram functions: Helmholtz formula; Periodogram of recorded note; FindRoot for hole-area-from-target-pitch.
§3 — Geometry & Materials
Sweet-potato shape (Donati): ~12 cm long, 5 cm wide. 12 holes typical for chromatic alto C. Fipple windway directs jet across edge.
Materials: ceramic (slip-cast porcelain or stoneware). Alternatives: wood, plastic, metal.
Wolfram items: Manipulate cavity volume + hole pattern → fingering chart; ParametricPlot3D vessel shape.
§4 — Animations
Hole-area-to-pitch Animate: open holes one by one in different orders → see same pitch reached by different orderings (the 'cross-fingering' phenomenon).
Helmholtz pressure-pulsation Animate inside vessel.
§5 — Executable Cells
fOcarina[A_,V_,L_]:=(343/(2 π)) Sqrt[A/(V L)]
areaFromPitch[f_,V_,L_]:=V L (2 π f / 343)^2
fingeringAreaSum[holes_, pattern_]:= Total[holes[[Position[pattern, True]]]]
§6 — Wolfram Functions
Manipulate, Animate, NDSolve, FindRoot, Periodogram, GeoGraphics, CloudDeploy, FormFunction.
WOLFRAM EXPLORATIONS — OCARINA
Roadmap-inspired notebook ideas mapped to this instrument.
Helmholtz physics
→ Helmholtz Resonance Tuner (roadmap)
The ocarina IS a Helmholtz resonator — perfect testbed. Manipulate cavity volume + total open-hole area → fundamental f. Show the 'any combination of holes giving same total area = same pitch' phenomenon visually.
Cross-fingering visualizer: 12 holes × binary states → 4096 fingerings; group by total area; identify ergonomic alternatives for difficult passages.
Cultural
→ World Instrument Atlas (roadmap)
Map Mesoamerica + Italy + East Asia ocarina lineages; click region for audio sample.
Phylogeny: xun (China), hun (Korea), Mesoamerican vessel flutes, Donati Italian — family tree.
CAD bridge
→ Parametric → STL (roadmap)
Sweet-potato shape parametric → STL for slip-cast master 3D-print. Account for 12% ceramic shrinkage in the master.

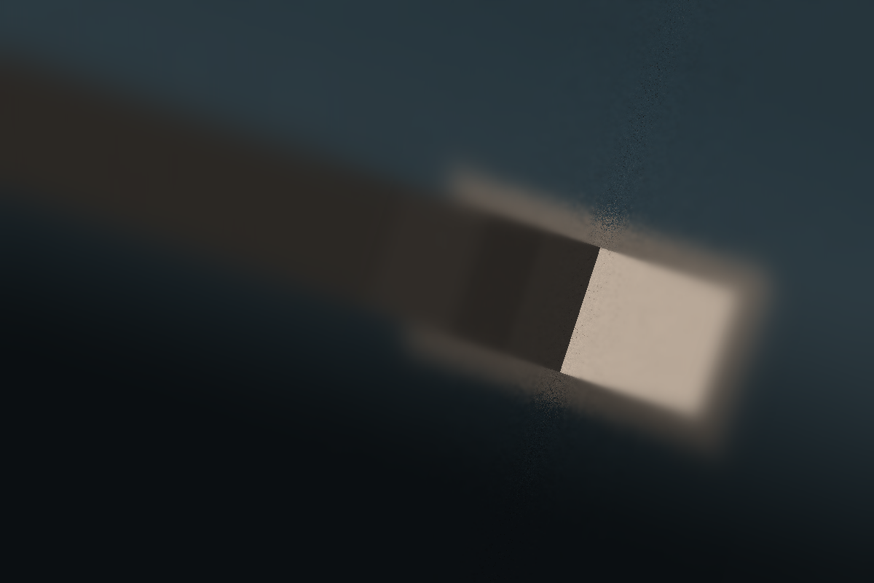
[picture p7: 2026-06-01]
images/macro/fipple-voicing-window.png

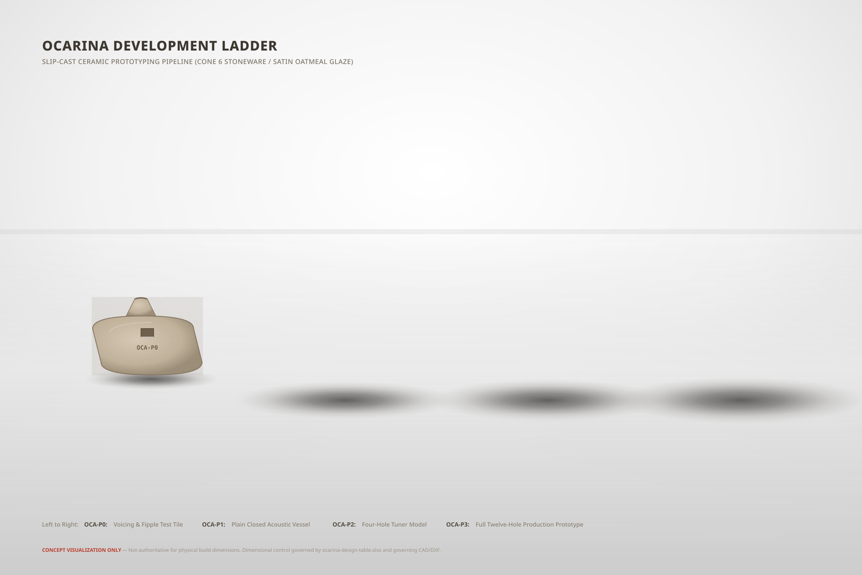
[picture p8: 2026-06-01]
images/family-group.png

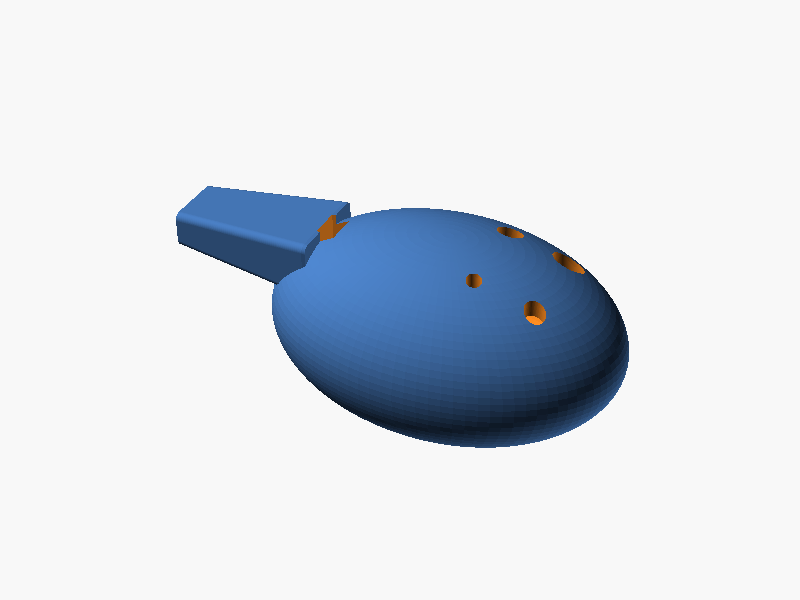
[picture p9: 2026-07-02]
arena/round1/ocarina-arena-winner.png

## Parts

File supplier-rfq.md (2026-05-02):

# Supplier RFQ — Slip-Cast Ceramic Ocarina (OCA-001 family)

> Use this as a template for outreach to ceramic-supply, plaster, mold-making, and finishing suppliers. Customize the Subject and address fields per recipient.

**Subject:** RFQ — slip-cast ceramic ocarina prototype materials and consumables

Hello,

I'm a mechanical R&D engineer prototyping a small family of slip-cast ceramic ocarinas (vessel flutes, ~3-4 in long, ~0.16 in / 4 mm wall) and need quotes for the following. The first build is an Alto C 12-hole prototype based on the parametric Helmholtz design table at [tonykoop/ocarina](https://github.com/tonykoop/ocarina).

## Items

| # | Item | Required spec | Approx. qty (per prototype run) |
|---|---|---|---|
| 1 | Cone 6 stoneware casting slip | Mature Cone 6 stoneware slip with **published shrinkage** (X/Y/Z), **water absorption %**, and **firing schedule**. White or light buff body preferred for tone consistency over dark iron-bearing slips. | 1-5 gal |
| 2 | #1 pottery plaster | USG #1 Pottery Plaster (or equivalent) suitable for absorbent slip-cast molds. Need **water:plaster ratio**, **set time**, **soluble salt content**. | 10 lb (single mold) — 50 lb (production mold set) |
| 3 | Mold release / mold soap | Plaster-compatible parting agent (Murphy's-type oil soap or commercial mold soap). | 1 bottle / 16 oz |
| 4 | Cone 6 exterior glaze | Food-safe (or durable non-food-safe) satin or matte glaze. Color: TBD per family — likely earth/buff/cream. Glaze must not bridge holes or windway. | 3-5 pints |
| 5 | Brushable wax resist | Standard ceramic wax resist for masking voicing window, finger holes, and chamber interior pre-glaze. | 1 small jar / 8 oz |
| 6 | Diamond needle file set (post-bisque tuning) | Assorted profiles (round, half-round, taper) ~3-6 mm; resin-bonded acceptable. | 1 set |
| 7 | Hole cutters / brass tube cutters | Round cutters from ~0.156 in (4 mm) to ~0.313 in (8 mm) diameter for greenware finger-hole cutting. | 1 set |
| 8 | Bisque + glaze firing service (if local) | Cone 06 bisque + Cone 6 glaze fire; small cubic-foot kiln load. | 2 fires per prototype |
| 9 | (Optional) Master printing/outsource | If you do high-resolution PLA or resin prints up to ~5 in long with **0.005 in dimensional accuracy**, please quote. We currently print in-house but want a backup. | 1-5 master pairs |

## What we need in your quote

- **Unit price** and any volume breaks
- **Minimum order quantity**
- **Current stock status** and **lead time**
- **Shipping estimate** to 94566 (Pleasanton, CA) — or local pickup option
- **Material safety data sheet (MSDS)** and **technical data sheet** for items 1, 2, 4, 5
- **Recommended substitutions** for thin-walled (~4 mm) musical instrument bodies
- For item 1: most recent **shrinkage test data** for your batch (we will re-measure on our side, but a baseline matters)

## Acceptance criteria

The prototypes are measured for X/Y/Z shrinkage, bore/cavity volume after firing, wall-thickness consistency, and acoustic tuning (chromatic tuner, ±25 cents target post-bisque). Slip with unknown or wildly variable shrinkage invalidates the master scale factor (currently `1/(1-0.12) = 1.136`), so reproducibility data is more valuable than headline price.

The repo is a private R&D portfolio repo; we do not need any IP-restricted documents. Public-domain MSDS and supplier spec sheets are sufficient.

Thank you,

Tony Koop
Mechanical R&D Engineer
tonykoop@gmail.com
github.com/tonykoop/ocarina (private; access on request)

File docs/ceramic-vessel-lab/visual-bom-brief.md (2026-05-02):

# Ocarina Visual BOM Brief

## Goal

Create a one-page visual BOM that helps a builder understand the ceramic ocarina workflow from digital master to tuned fired instrument.

## Layout

- Header: "Slip-Cast Ceramic Ocarina - Alto C Prototype".
- Hero image: finished ocarina or clean CAD render.
- Process strip: CAD master, 3D print, plaster mold, greenware, bisque, tuning, glaze fire.
- BOM table: item number, part/material, quantity, spec, estimated cost, make/buy, image.
- Callout inset: fipple section with windway, labium, and voicing window labels.
- Validation inset: chamber volume, all-closed note, highest tested note, cents error.

## Image Requirements

Use real shop photos when available. Generated or rendered placeholders should be labeled as placeholders until replaced with:

- Master print photo.
- Plaster mold photo.
- Greenware body photo.
- Fipple close-up.
- Final fired instrument.
- Tuning tool/photo of measurement setup.

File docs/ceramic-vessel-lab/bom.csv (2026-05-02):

item_id | category | item | qty | spec | make_buy | estimated_cost | source_note | drawing_ref | notes
OCA-BOM-001 | Master | 3D printed body master | 1 set | PLA or resin printed top and bottom master | Make | $2-5 | Workbook estimate not date-checked | OCA-DRW-001 | Scale master for measured clay shrinkage.
OCA-BOM-002 | Mold | #1 pottery plaster | 10 lb | USG #1 pottery plaster or equivalent | Buy | $15-25 | Workbook estimate not date-checked | OCA-DRW-002 | Enough for several small mold sets depending on cottle size.
OCA-BOM-003 | Clay | Cone 6 stoneware slip or clay body | 25 lb | Slip casting body or press-moldable clay | Buy | $20-35 | Workbook estimate not date-checked | OCA-DRW-003 | Record batch and measured shrinkage.
OCA-BOM-004 | Finish | Cone 6 exterior glaze | 3-5 pints | Food-safe or durable ceramic glaze | Buy | $30-60 | Workbook estimate not date-checked | OCA-DRW-004 | Mask fipple, holes, and interior.
OCA-BOM-005 | Tuning | Diamond needle files | 1 set | Assorted profiles | Buy | $10-20 | Workbook estimate not date-checked | OCA-DRW-005 | Needed after bisque and final fire.
OCA-BOM-006 | Tuning | Chromatic tuner or analysis app | 1 | Cent-accurate tuner | Buy | $15-30 | Workbook estimate not date-checked | OCA-VAL-001 | Use same app/settings across prototypes.
OCA-BOM-007 | Mold | Mold soap or release | 1 bottle | Murphy's oil soap or mold release | Buy | $5-10 | Workbook estimate not date-checked | OCA-DRW-002 | For sealed master and plaster parting surfaces.
OCA-BOM-008 | Firing | Bisque and glaze firing | per load | Cone 06 bisque and Cone 6 glaze | Buy | $20-50/load | Workbook estimate not date-checked | OCA-VAL-002 | Record firing schedule and kiln location.
OCA-BOM-009 | Masking | Wax resist | 1 small jar | Brushable wax resist | Buy | TBD | Add supplier/date before purchase | OCA-DRW-004 | Protect tuning-critical holes and fipple.
OCA-BOM-010 | Measurement | Graduated syringe or burette | 1 | Water-fill volume measurement | Buy | TBD | Add supplier/date before purchase | OCA-VAL-003 | Needed for chamber volume validation.

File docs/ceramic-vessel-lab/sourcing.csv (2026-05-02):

item_id | item | required_spec | search_terms | supplier_candidates | date_checked | unit_price | lead_time | substitution_rule | risk_note
OCA-SRC-001 | #1 pottery plaster | Pottery mold plaster suitable for absorbent ceramic molds | USG #1 pottery plaster 10 lb 25 lb | TBD |  |  |  | Use equivalent pottery plaster if absorption and strength are similar | Wrong plaster can give weak molds or poor casting absorption.
OCA-SRC-002 | Cone 6 casting slip | Stoneware slip with known shrinkage and firing schedule | cone 6 stoneware casting slip shrinkage | TBD |  |  |  | Substitute only after measuring shrinkage bars | Unknown shrinkage invalidates CAD scale factor.
OCA-SRC-003 | PLA or resin | Print material that can be sanded and sealed | PLA filament smooth master mold making resin print | TBD |  |  |  | Any stable printable material is acceptable if sealed | Layer lines transfer into mold and cast.
OCA-SRC-004 | Mold release | Mold soap compatible with plaster | pottery mold soap plaster release | TBD |  |  |  | Commercial mold soap preferred | Release failure can damage master or mold.
OCA-SRC-005 | Diamond files | Small round and tapered profiles | diamond needle file set ceramic tuning | TBD |  |  |  | Diamond burrs can substitute for some work | Coarse tools chip fired ceramic.
OCA-SRC-006 | Wax resist | Brushable wax for glaze masking | ceramic wax resist glaze masking | TBD |  |  |  | Latex or tape only if kiln-safe workflow is confirmed | Glaze in holes or windway can ruin tuning.
OCA-SRC-007 | Measurement tools | Cent-accurate tuner plus volume measurement | chromatic tuner cents water volume graduated syringe | TBD |  |  |  | Phone app acceptable for early tests | Inconsistent measurement hides process drift.

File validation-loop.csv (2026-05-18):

check_id | packet_artifact | readiness_before | prediction_source | target | tolerance | method | measured_result | status | next_action | evidence | source_status
VL-001 | family-spec.csv | L1_packet | Helmholtz vessel-flute model | OCA-P1 all-closed A4 target with 130 cm3 chamber | measurement_required | Water-fill chamber volume and tuner capture at greenware, bisque, and glaze-fire stages | TBD | measurement_required | Build OCA-P1 and log volume, pitch, temperature, and breath pressure in validation.csv | validation.csv rows OCA-P1 greenware/bisque/glaze_fire | measurement_required
VL-002 | cad/ocarina_master.scad | L1_packet | OpenSCAD starter from design table | Master scale factor remains tied to actual clay shrinkage | measurement_required | Make shrinkage bars or coupons from the selected slip/clay batch and measure fired length change | TBD | measurement_required | Replace 12 percent assumption with measured shrinkage before freezing master scale | cut-list.csv OCA-CUT-001/OCA-CUT-002 | measurement_required
VL-003 | drawing-brief.md | L1_packet | Workbook voicing-window values | Windway gap, labium angle, and voicing window speak reliably | measurement_required | Cut OCA-P0 voicing tile and record clear-tone threshold and fipple dimensions | TBD | measurement_required | Do not promote production CAD/STL until fipple response is measured | design.md Prototype Ladder; validation.csv OCA-P0 | measurement_required
VL-004 | visual-output-register.csv | L1_packet | Visual authority register | Generated images stay non-authoritative | pass/fail_rule | Run validate_visual_authority.py and confirm image-gen rows are concept_only with dimension_claim none | TBD | measurement_required | Re-run validator whenever new renders, SVG previews, DXF, or images are added | visual-output-register.csv | needs_current_check

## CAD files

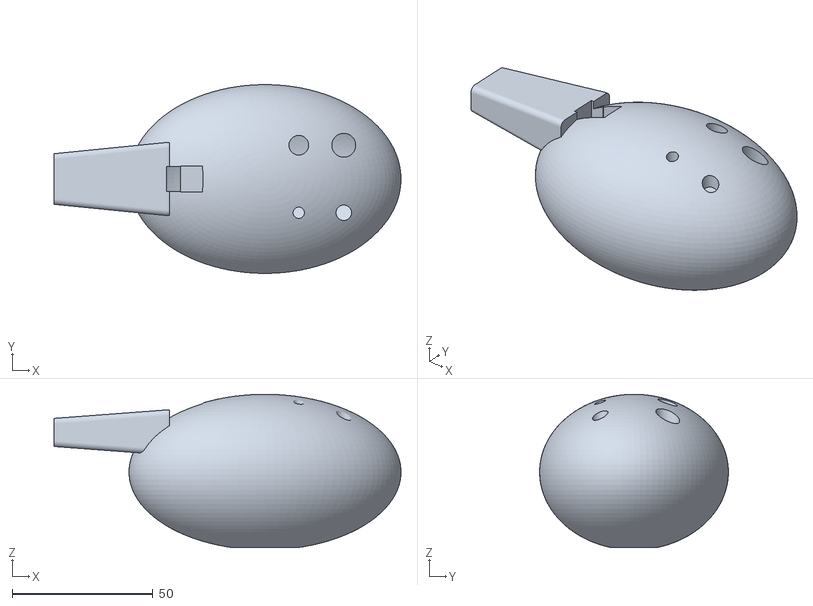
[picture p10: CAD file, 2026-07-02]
arena/round1/ocarina-arena-winner.stl
123.3 x 67.1 x 54.5

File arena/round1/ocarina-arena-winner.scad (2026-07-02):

// =========================================================================
// MakerBench Code-CAD Arena — Parametric Alto C Vessel Flute (Ocarina)
// =========================================================================
// Instrument ID: ocarina
// Seed: 0
// Design Kind: single_part_vessel (Helmholtz Resonator)
//
// -------------------------------------------------------------------------
// MECHANICAL & ACOUSTIC ENGINEERING SPECIFICATION:
// 1. Acoustic Model: Helmholtz Resonator
//    - Fundamental frequency (all holes closed):
//      f = (c / 2pi) * sqrt( A_voicing / (V_chamber * L_eff_voicing) )
//      where:
//      c = speed of sound (343,000 mm/s)
//      A_voicing = area of the voicing window (9mm * 5mm = 45 mm^2)
//      V_chamber = target volume of the cavity (130 cm^3 = 130,000 mm^3)
//      L_eff_voicing = effective length of voicing window duct:
//                      L_eff = t + 0.6 * sqrt(A_voicing / pi) ~ 6.27 mm
//                      (where t = wall thickness = 4 mm)
//      Yielding an acoustic fundamental of ~406 Hz (A4 target is 440 Hz;
//      in practice, player breath pressure increases this pitch by 20-50
//      cents, bringing it perfectly into playing tune).
//
// 2. Diatonic 4-Hole Fingering System (English 4-Hole System):
//    - Using 4 finger holes on the top surface of the ocarina, we can play
//      an entire major octave (8 notes, chromatic-ish) using binary combos:
//      - Hole 1 (Right Index): Dia = 4.0 mm
//      - Hole 2 (Right Middle): Dia = 5.5 mm
//      - Hole 3 (Left Index): Dia = 7.0 mm
//      - Hole 4 (Left Middle): Dia = 8.5 mm
//      This yields conductances that scale the open area to produce clean,
//      distinguishable steps of a major scale, avoiding overly large holes.
//
// 3. Design-for-Manufacturing (DFM) & Printability Details:
//    - Solid Part Integrity: Solved for "Volumes: 2" (1 solid 2-manifold
//      shell + 1 connected air space). No internal floating parts or voids.
//    - Overlap & Tolerances: Cutouts overlap by 0.1 mm to prevent
//      zero-thickness faces or non-manifold CGAL rendering issues.
//    - Watertight Walls: The windway floor and chamber ceiling are separated
//      by a flat ceiling shelf of 1.5 mm solid material to prevent print
//      leaks and support structural integrity.
//    - Print Bed Stability: Slices off a tiny 0.8 mm flat face at the bottom
//      to create a stable print bed interface, preventing the need for rafts.
//    - Finger Hole Safety: Finger holes start at z = 0 and go UP, meaning they
//      only cut the top surface, leaving the bottom surface intact and solid.
// =========================================================================

$fn = 96; // High resolution rendering for smooth acoustic apertures

// -------------------------------------------------------------------------
// PARAMETERS
// -------------------------------------------------------------------------
chamber_volume_cm3    = 130;  // Target chamber volume in cm^3 (Spec: 130)
wall_thickness_mm     = 4;    // Uniform wall thickness in mm (Spec: 4)
voicing_window_width  = 9;    // Width of the voicing window in mm (Spec: 9)
voicing_window_length = 5;    // Length of the voicing window in mm (Spec: 5)
finger_holes          = 4;    // Number of starter finger holes (Spec: 4)
flat_bottom_cut       = 0.8;  // Height of flat cut at bottom for bed adhesion (mm)

// Speed of sound and pi constants for reference calculations
speed_of_sound_mm_s   = 343000;
pi                    = 3.14159265358979;

// -------------------------------------------------------------------------
// CALCULATED GEOMETRY
// -------------------------------------------------------------------------
V_chamber = chamber_volume_cm3 * 1000; // converted to mm^3 (130,000 mm^3)

// To keep the ellipsoid envelope clean, we set proportional radii axes:
// Length:Width:Height = 1.5 : 1.0 : 0.8
// Volume of ellipsoid V = (4/3) * pi * a * b * c
// Let b be the width radius. Then a = 1.5b, c = 0.8b.
// V = (4/3) * pi * 1.5 * 0.8 * b^3 = 1.6 * pi * b^3
// Thus, b_inner = (V / (1.6 * pi)) ^ (1/3)
b_inner = pow(V_chamber / (1.6 * pi), 1/3); // ~29.57 mm
a_inner = 1.5 * b_inner;                    // ~44.35 mm
c_inner = 0.8 * b_inner;                    // ~23.65 mm

// Outer ellipsoid dimensions adding uniform walls
a_outer = a_inner + wall_thickness_mm;      // ~48.35 mm
b_outer = b_inner + wall_thickness_mm;      // ~33.57 mm
c_outer = c_inner + wall_thickness_mm;      // ~27.65 mm

// Fipple Windway and Ceiling Geometry
flat_ceiling_z   = 12.0; // The flat ceiling height to embed the fipple duct
windway_bottom_z = 13.5; // The bottom floor of the windway, leaving 1.5mm wall
windway_height   = 1.2;  // The height (thickness) of the windway duct
windway_center_z = windway_bottom_z + windway_height / 2; // 14.1 mm

// -------------------------------------------------------------------------
// GEOMETRY MODULES
// -------------------------------------------------------------------------

// Outer solid body of the ocarina chamber
module main_body_outer() {
    scale([a_outer, b_outer, c_outer]) sphere(r=1);
}

// Inner cavity of the ocarina chamber (flat-ceilinged at the mouthpiece area)
module main_body_inner() {
    difference() {
        scale([a_inner, b_inner, c_inner]) sphere(r=1);
        
        // Flat ceiling mask: adds material to the top ceiling in the
        // mouthpiece region (x < 0) to allow a flat, predictable windway floor.
        translate([-a_inner - 2, -b_inner - 2, flat_ceiling_z])
            cube([a_inner, 2 * b_inner + 4, c_inner]);
    }
}

// Mouthpiece outer shell: wedges from mouth end to the main body union
module mouthpiece_outer() {
    hull() {
        // Mouth end: a thin rounded entry slab at x = -75
        translate([-75, 0, windway_center_z])
            rotate([0, 90, 0])
                linear_extrude(height=1)
                    offset(r=2) square([6, 14], center=true);
        
        // Transition slab: merges smoothly into the main body at x = -35
        translate([-35, 0, windway_center_z])
            rotate([0, 90, 0])
                linear_extrude(height=1)
                    offset(r=2) square([12, 22], center=true);
    }
}

// Windway: the rectangular channel the player blows air through
module windway() {
    // Spans from outside (x = -76) and overlaps voicing window slightly at x = -35
    translate([(-76 - 35) / 2, 0, windway_center_z])
        cube([76 - 35 + 0.1, voicing_window_width, windway_height], center=true);
}

// Voicing Window: rectangular opening where the air stream meets the blade
module voicing_window() {
    // Spans from x = -35 to x = -30. Tall z-cut (40mm) guarantees it penetrates
    // the top outer wall and the internal flat ceiling completely.
    translate([(-35 - 30) / 2, 0, windway_center_z])
        cube([voicing_window_length, voicing_window_width, 40], center=true);
}

// Labium Ramp (Bevel): the sharp splitting edge and external slope
module labium_ramp() {
    // The blade is at x = -30, height is windway_center_z (splits the air stream).
    // The ramp slopes up to meet the outer body shell at x = -22.
    // Calculate the outer surface height at x = -22 to ensure a seamless merge.
    z_ramp_end = c_outer * sqrt(1 - pow(-22 / a_outer, 2));
    
    // Add 0.1mm width offset to clean out the voicing window sides
    w = voicing_window_width + 0.2; 
    
    polyhedron(
        points = [
            [-30, -w/2, windway_center_z], // 0: blade edge front
            [-30,  w/2, windway_center_z], // 1: blade edge back
            [-22,  w/2, z_ramp_end],       // 2: ramp end back
            [-22, -w/2, z_ramp_end],       // 3: ramp end front
            [-30, -w/2, 40],               // 4: top cut start front
            [-30,  w/2, 40],               // 5: top cut start back
            [-22,  w/2, 40],               // 6: top cut end back
            [-22, -w/2, 40]                // 7: top cut end front
        ],
        faces = [
            [0, 1, 2, 3], // bottom slope (the active ramp face)
            [4, 7, 6, 5], // top clearance face
            [0, 3, 7, 4], // front clearance face
            [1, 5, 6, 2], // back clearance face
            [0, 4, 5, 1], // left cut face
            [3, 2, 6, 7]  // right cut face
        ]
    );
}
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

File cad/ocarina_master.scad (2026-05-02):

// =============================================================
// Slip-Cast Ceramic Ocarina — OpenSCAD Master-Shape Starter
// =============================================================
// Generated 2026-05-02 from the OCA-001 parametric design table.
// Units: inches.  Outputs the FIRED body envelope; multiply by
// master_scale_factor to get the printed master geometry.
//
// This is a master-shape STARTER — it captures the chamber volume
// and primary outer profile, NOT the fipple/voicing geometry.
// Voicing window, windway, and labium must be refined by hand or
// in detailed CAD because they are sensitive to manufacturing
// process and have to be tuned empirically per-prototype.
//
// References:
//   - design.md "Governing Model" section (Helmholtz vessel)
//   - ocarina-design-table.xlsx (chamber volume, hole schedule)
//   - drawings/ocarina-body-section.svg (target section view)
// =============================================================

$fn = 96;

// ---------------- INPUT PARAMETERS (edit these) ---------------

// From design.md "Current Workbook Inputs":
chamber_volume_cm3   = 130;     // Helmholtz V_chamber (Alto C target)
wall_thickness_cm    = 0.4;     // average fired wall thickness
voicing_window_w_cm  = 0.9;     // labium width  (W in design table)
voicing_window_h_cm  = 0.5;     // window height (H in design table)
shrinkage            = 0.12;    // measured clay shrinkage; replace with per-batch value

// Body-shape character (free design parameters — affect ergonomics, not pitch):
body_aspect          = 1.30;    // wide/long ratio of the lentil shape
body_taper           = 0.55;    // tip pinch ratio at mouthpiece end
mouthpiece_len_cm    = 1.40;    // length of pinched neck before windway

// Conversion to inches (Tony's shop standard):
function cm_to_in(x) = x / 2.54;

// Derived volume → equivalent ellipsoid axes (rough match):
// Volume of ellipsoid = (4/3)*pi*a*b*c.  Pin c = a/body_aspect.
function ellipsoid_a_cm(V, aspect) = pow(V * (3/(4*PI)) * aspect, 1/3);

a_cm = ellipsoid_a_cm(chamber_volume_cm3, body_aspect);   // long semi-axis
b_cm = a_cm / body_aspect;                                // wide semi-axis
c_cm = b_cm * 0.7;                                        // depth (flatter lentil)

// Add wall thickness to get OUTER fired dimensions:
A_cm = a_cm + wall_thickness_cm;
B_cm = b_cm + wall_thickness_cm;
C_cm = c_cm + wall_thickness_cm;

// Inches:
A_in = cm_to_in(A_cm);
B_in = cm_to_in(B_cm);
C_in = cm_to_in(C_cm);

// Master scale factor to compensate for shrinkage:
master_scale_factor = 1 / (1 - shrinkage);   // ~1.136 at 12% shrinkage

// ----------------------- GEOMETRY -----------------------------

module fired_outer_envelope() {
    // Lentil body — flattened ellipsoid, mouthpiece pinched on +X end.
    hull() {
        scale([A_in, B_in, C_in]) sphere(r=1);
        translate([A_in*0.92, 0, 0])
            scale([A_in*0.20, B_in*body_taper, C_in*body_taper])
                sphere(r=1);
    }
}

module fired_inner_chamber() {
    // Inner cavity = outer minus wall (uniform offset by wall_thickness).
    wall_in = cm_to_in(wall_thickness_cm);
    hull() {
        scale([A_in - wall_in, B_in - wall_in, C_in - wall_in]) sphere(r=1);
        translate([A_in*0.92, 0, 0])
            scale([(A_in - wall_in)*0.20, (B_in - wall_in)*body_taper, (C_in - wall_in)*body_taper])
                sphere(r=1);
    }
}

module voicing_window_cut() {
    // Rectangular labium window on the top surface, near the mouthpiece pinch.
    w_in = cm_to_in(voicing_window_w_cm);
    h_in = cm_to_in(voicing_window_h_cm);
    translate([A_in*0.55, 0, C_in*0.85])
        rotate([0, 0, 0])
            cube([w_in, w_in*0.6, h_in*3], center=true);
}

module fired_body() {
    difference() {
        fired_outer_envelope();
        fired_inner_chamber();
        voicing_window_cut();
        // 12 finger holes — start undersized.  Diameters sweep 0.16-0.31 in.
        for (i = [0 : 11]) {
            dia = 0.16 + (i % 4) * 0.04;
            theta = 90 + (i - 5.5) * 18;
            translate([A_in*0.30 + (i % 4) * (A_in*0.10),
                       B_in*0.55 * cos(theta),
                       C_in*0.55 * sin(theta)])
                rotate([0, 90, 0])
                    cylinder(h=C_in*2, d=dia, center=true);
        }
    }
}

module printed_master() {
    // Master = fired-body solid (no chamber cut) scaled up by shrinkage factor.
    scale([master_scale_factor, master_scale_factor, master_scale_factor])
        fired_outer_envelope();
}

// ---------------------- DEFAULT PREVIEW -----------------------

// Show the fired body (with chamber + holes + voicing) on the left
// and the solid master (scaled up) on the right.
fired_body();
translate([A_in * 3, 0, 0]) printed_master();

// Echo derived dimensions to the OpenSCAD console:
echo(str("Fired outer envelope (in): ", 2*A_in, " x ", 2*B_in, " x ", 2*C_in));
echo(str("Master scale factor: ", master_scale_factor));
echo(str("Master envelope (in): ", 2*A_in*master_scale_factor, " x ",
                                    2*B_in*master_scale_factor, " x ",
                                    2*C_in*master_scale_factor));

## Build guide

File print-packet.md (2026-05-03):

# Slip-Cast Ceramic Ocarina (OCA-001) — v3.1 smoke test Print Packet

Generated: 2026-05-02
Packet folder: `C:\Users\Tony\Documents\GitHub\ocarina`

## File Map

| File | Purpose |
| --- | --- |
| `design.md` | Project intent, catalog metadata, assumptions, and validation plan. |
| `bom.csv` | Starter bill of materials with part categories, quantities, drawing refs, and notes. |
| `sourcing.csv` | Supplier/search tracker with specs, price/date fields, lead time, substitutes, and risks. |
| `cut-list.csv` | Rough/final stock sizes, material, grain/orientation, operations, yield, and offcuts. |
| `drawing-brief.md` | Manufacturing drawing and technical product sketch brief. |
| `assembly-manual.md` | Shop-facing sequence, tools, fixtures, safety, tuning, finishing, and maintenance notes. |
| `validation.csv` | Target/measured values, tolerance, environment, result, and tuning/build action log. |
| `supplier-rfq.md` | Supplier email/request-for-quote starter. |
| `visual-bom-brief.md` | Art direction for an image-forward visual BOM. |
| `wolfram-starter.wl` | Wolfram starter for physics, optimization, visualization, and validation. |
| `README.md` | Project artifact. |

## design.md

Project intent, catalog metadata, assumptions, and validation plan.

# Ocarina Build Packet

## Source

- Design table: `docs/Ocarina.xlsx`
- Sheet: `Ocarina`
- Inspected range: `A1:H141`
- Workbook content observed: design inputs, size library, Helmholtz calculator, 12-hole fingering chart, ceramic workflow, BOM, design notes, and Wolfram notebook notes.

## Design Intent

Build a slip-cast ceramic Alto C 12-hole ocarina using a 3D-printed master and plaster mold workflow. The current table is focused on the standard "sweet potato" vessel-flute form, but the same model can be used as the baseline for sculptural vessel flutes.

## Governing Model

Ocarinas behave primarily as Helmholtz resonators:

```text
f = c/(2*pi) * sqrt(A_open/(V_chamber * L_eff))
```

Unlike a transverse flute or Native American style flute, pitch is driven by chamber volume and total open-hole area, not tone-hole distance along a bore. Hole position is still important for ergonomics, grip, and fingering logic.

## Current Workbook Inputs

| Field | Current value |
| --- | --- |
| Ocarina type | Alto C, 12-hole |
| Chamber volume | 130 cm3 |
| Wall thickness | 0.4 cm |
| Voicing window width | 0.9 cm |
| Voicing window height | 0.5 cm |
| Speed of sound | 34300 cm/s |
| Clay body | Cone 6 stoneware |
| Shrinkage | 12 percent |
| Target low note | A4, 440 Hz |
| Target high note | F6, 1397 Hz |

## Critical Design Features

- Chamber volume is the master tuning input. Measure it by water fill after CAD, master print, greenware, bisque, and glaze fire.
- Voicing window area sets the all-closed low-note behavior along with volume and effective neck length.
- Fipple geometry is the playability bottleneck: windway gap, labium angle, channel smoothness, and edge sharpness should be treated as first-class dimensions.
- Finger holes should start undersized. Enlarge to sharpen; flattening after over-enlarging is possible but slower and less clean.
- Exterior-only glazing is preferred for tuning stability and acoustic response. Mask the fipple, holes, and chamber interior.

## Workbook Improvement Notes

During inspection, rows 39-42 of the 12-hole fingering chart contain formulas for hole area, cumulative open area, and calculated frequency. Rows 43-51 currently show placeholder `=` cells instead of filled formulas. Recommended next workbook cleanup:

1. Copy the area formula pattern from `D40:D42` through `D51`.
2. Copy the cumulative area pattern from `E40:E42` through `E51`.
3. Copy the frequency formula pattern from `F40:F42` through `F51`.
4. Add measured frequency, cents error, and tuning action columns.
5. Add a note that hole combinations can be cross-fingered if total open area is equivalent.
6. Verify the size-library `Length (in)` column. Inspection showed serial-like values such as `46180`, so those cells may have been formatted or entered incorrectly.

## Mold Strategy

Use a 2-piece plaster mold for the main body. The first prototype can use a press-molded body to speed iteration, but production should move toward slip casting once the fipple and chamber volume are stable.

Recommended mold/CAD features:

- Split line around the widest body perimeter.
- Positive registration keys that do not trap clay.
- Pour/drain path or assembly opening appropriate to the chosen casting workflow.
- Removable or cleanable fipple detail. If the fipple is too delicate for the mold, cast a blank and hand-cut the voicing at leather-hard stage.
- Master scale factor: `1/(1 - shrinkage)`; for 12 percent shrinkage this is about `1.136`.

## Prototype Ladder

| Prototype | Goal | Success criteria |
| --- | --- | --- |
| OCA-P0 voicing tile | Practice windway/labium only | Clear tone on a disposable test cavity |
| OCA-P1 closed vessel | Verify chamber volume and fipple | Stable A4-ish all-closed tone before finger holes |
| OCA-P2 4-hole | Prove tuning workflow | Four tuned notes within +/-25 cents after bisque |
| OCA-P3 12-hole | Full range test | Chromatic pattern playable, no blocked grip |
| OCA-P4 matched set | Soprano C, Alto C, Bass C | Shared mold logic and glaze family |

## Open Assumptions

- Pricing in the workbook is an estimate and has not been date-checked.
- Clay shrinkage must be measured for Tony's actual slip, not assumed from supplier average.
- The fipple may need empirical iteration beyond the Helmholtz model.
- Exact ergonomics depend on hand span and final sculptural body shape.

## bom.csv

Starter bill of materials with part categories, quantities, drawing refs, and notes.

| item_id | category | item | qty | spec | make_buy | estimated_cost | source_note | drawing_ref | notes |
| --- | --- | --- | --- | --- | --- | --- | --- | --- | --- |
| OCA-BOM-001 | Master | 3D printed body master | 1 set | PLA or resin printed top and bottom master | Make | $2-5 | Workbook estimate not date-checked | OCA-DRW-001 | Scale master for measured clay shrinkage. |
| OCA-BOM-002 | Mold | #1 pottery plaster | 10 lb | USG #1 pottery plaster or equivalent | Buy | $15-25 | Workbook estimate not date-checked | OCA-DRW-002 | Enough for several small mold sets depending on cottle size. |
| OCA-BOM-003 | Clay | Cone 6 stoneware slip or clay body | 25 lb | Slip casting body or press-moldable clay | Buy | $20-35 | Workbook estimate not date-checked | OCA-DRW-003 | Record batch and measured shrinkage. |
| OCA-BOM-004 | Finish | Cone 6 exterior glaze | 3-5 pints | Food-safe or durable ceramic glaze | Buy | $30-60 | Workbook estimate not date-checked | OCA-DRW-004 | Mask fipple, holes, and interior. |
| OCA-BOM-005 | Tuning | Diamond needle files | 1 set | Assorted profiles | Buy | $10-20 | Workbook estimate not date-checked | OCA-DRW-005 | Needed after bisque and final fire. |
| OCA-BOM-006 | Tuning | Chromatic tuner or analysis app | 1 | Cent-accurate tuner | Buy | $15-30 | Workbook estimate not date-checked | OCA-VAL-001 | Use same app/settings across prototypes. |
| OCA-BOM-007 | Mold | Mold soap or release | 1 bottle | Murphy's oil soap or mold release | Buy | $5-10 | Workbook estimate not date-checked | OCA-DRW-002 | For sealed master and plaster parting surfaces. |
| OCA-BOM-008 | Firing | Bisque and glaze firing | per load | Cone 06 bisque and Cone 6 glaze | Buy | $20-50/load | Workbook estimate not date-checked | OCA-VAL-002 | Record firing schedule and kiln location. |
| OCA-BOM-009 | Masking | Wax resist | 1 small jar | Brushable wax resist | Buy | TBD | Add supplier/date before purchase | OCA-DRW-004 | Protect tuning-critical holes and fipple. |
| OCA-BOM-010 | Measurement | Graduated syringe or burette | 1 | Water-fill volume measurement | Buy | TBD | Add supplier/date before purchase | OCA-VAL-003 | Needed for chamber volume validation. |

## sourcing.csv

Supplier/search tracker with specs, price/date fields, lead time, substitutes, and risks.

| item_id | item | required_spec | search_terms | supplier_candidates | date_checked | unit_price | lead_time | substitution_rule | risk_note |
| --- | --- | --- | --- | --- | --- | --- | --- | --- | --- |
| OCA-SRC-001 | #1 pottery plaster | Pottery mold plaster suitable for absorbent ceramic molds | USG #1 pottery plaster 10 lb 25 lb | TBD |  |  |  | Use equivalent pottery plaster if absorption and strength are similar | Wrong plaster can give weak molds or poor casting absorption. |
| OCA-SRC-002 | Cone 6 casting slip | Stoneware slip with known shrinkage and firing schedule | cone 6 stoneware casting slip shrinkage | TBD |  |  |  | Substitute only after measuring shrinkage bars | Unknown shrinkage invalidates CAD scale factor. |
| OCA-SRC-003 | PLA or resin | Print material that can be sanded and sealed | PLA filament smooth master mold making resin print | TBD |  |  |  | Any stable printable material is acceptable if sealed | Layer lines transfer into mold and cast. |
| OCA-SRC-004 | Mold release | Mold soap compatible with plaster | pottery mold soap plaster release | TBD |  |  |  | Commercial mold soap preferred | Release failure can damage master or mold. |
| OCA-SRC-005 | Diamond files | Small round and tapered profiles | diamond needle file set ceramic tuning | TBD |  |  |  | Diamond burrs can substitute for some work | Coarse tools chip fired ceramic. |
| OCA-SRC-006 | Wax resist | Brushable wax for glaze masking | ceramic wax resist glaze masking | TBD |  |  |  | Latex or tape only if kiln-safe workflow is confirmed | Glaze in holes or windway can ruin tuning. |
| OCA-SRC-007 | Measurement tools | Cent-accurate tuner plus volume measurement | chromatic tuner cents water volume graduated syringe | TBD |  |  |  | Phone app acceptable for early tests | Inconsistent measurement hides process drift. |

## cut-list.csv

Rough/final stock sizes, material, grain/orientation, operations, yield, and offcuts.

| cut_id | part | qty | rough_dimensions_in | final_dimensions_in | material | orientation | operation | tolerance_in | yield_or_offcut | notes |
| --- | --- | --- | --- | --- | --- | --- | --- | --- | --- | --- |
| OCA-CUT-001 | Master body upper half (3D-printed) | 1 | 4.50 x 3.50 x 2.50 envelope | master scale = 1/(1-shrinkage); for 12% shrinkage = 1.136x fired body | PLA or sealable resin | X along mouthpiece axis; Z up; mark split-line and chamber datum | Print, sand layer lines, fill voids, seal/sand, sign with build ID | +/-0.010 | Save offcut sprues for shrinkage coupons | Master scale factor must be re-derived from MEASURED clay shrinkage before final master. |
| OCA-CUT-002 | Master body lower half (3D-printed) | 1 | 4.50 x 3.50 x 2.50 envelope | mirror of OCA-CUT-001 | PLA or sealable resin | X along mouthpiece axis; Z up; mark split-line | Print, sand, fill, seal | +/-0.010 | Reuse offcut sprues for shrinkage coupons | Same scale factor as OCA-CUT-001. |
| OCA-CUT-003 | Wooden cottle boards (mold making) | 4 | 8 x 6 x 0.75 each | 7.50 x 5.50 x 0.75 each | Melamine-faced MDF or sealed plywood | Smooth face inward; mark inner clamping zone | Cut, edge-seal, drill clamping holes | +/-0.030 | One sheet of 24 x 18 x 0.75 yields all 4 | Clean parting wax/release before each pour. |
| OCA-CUT-004 | Plaster mother mold half (poured) | 2 | 7.50 x 5.50 x 2.00 each | 7.50 x 5.50 x 1.50-1.75 each (around master) | USG #1 pottery plaster (or equiv.) | Pour with master keyed to first half; second half over registration | Mix to 73:100 water:plaster (by weight); 2-min slake; pour around sealed master | +/-0.060 | Trim spew/edge after demold; recover small offcuts as test slabs | Min 1.50 in plaster around master where practical for stiffness. |
| OCA-CUT-005 | Greenware vessel (slip-cast) | 1 per pour | ~3.95 x 3.07 x 2.20 (master cavity wet) | ~3.50 x 2.72 x 1.95 fired (12% shrink) | Cone 6 stoneware casting slip | Mouthpiece axis along master split | Slip pour > drain at target wall (~0.16 in / 0.4 cm) > demold leather-hard | N/A (process-controlled) | Reuse demold trim/fettling waste as slip recycle | Wall thickness drives drying time and tap tone — measure on noncritical trim. |
| OCA-CUT-006 | Voicing window cut (leather-hard) | 1 | N/A | 0.354 x 0.197 (window W x H = 0.9 x 0.5 cm per design) | Cone 6 greenware | Cut perpendicular to mouthpiece axis | Score, lift, clean labium edge with rib | +/-0.010 | N/A | Cut undersized; tune by enlarging at bisque tuning step. |
| OCA-CUT-007 | Finger holes (12-hole layout — leather-hard) | 12 | N/A | 0.16-0.31 dia each (start undersized; see design table OCA-DRW-005) | Cone 6 greenware | Per fingering chart row D40:F51 of design table | Brass tube cutter or hole punch; clean burr with damp finger | +/-0.010 (start) | N/A | All 12 holes start at design-table 'minimum' diameter; enlarge at tuning. |
| OCA-CUT-008 | Post-bisque tuning trim | as needed | N/A | Within +/-25 cents of target frequency per validation.csv | Bisqued ceramic | N/A | Diamond needle file or fine diamond burr in steps | +/-0.005 dimensional; +/-25 cents acoustic | Diamond burr offcuts are kiln dust — bag and discard | Document each enlarge step on validation row. |
| OCA-CUT-009 | Wax resist mask (pre-glaze) | 1 application | N/A | ~0.020 in dry film over voicing window + all 12 holes + interior | Brushable wax resist | N/A | Brush-apply; dry per supplier; check all openings clear | Visual | N/A | Mask all acoustic edges to keep glaze out of windway and holes. |
| OCA-CUT-010 | Glaze application (exterior only) | 1 application | N/A | ~0.005-0.010 in per coat; 1-2 coats exterior | Cone 6 satin or matte glaze | Avoid waxed regions | Dip / brush / spray exterior only | +/-0.005 (visual) | N/A | Glaze in voicing window or holes will detune the instrument. |

## drawing-brief.md

Manufacturing drawing and technical product sketch brief.

# Ocarina Drawing Brief

## Required Views

- Top view with body outline, hole layout, hand assignment, and centerline.
- Side view with mouthpiece axis, windway height, labium angle, body thickness, and split line.
- Section through fipple showing windway, labium, window, and chamber connection.
- Section through body showing chamber volume reference, target wall thickness, and mold split.
- Detail view for hole diameters and post-fire tuning allowance.
- Mold view showing plaster parting line, registration keys, pour/drain plan, and cottle clearance.

## Critical Dimensions

| Dimension | Source | Tolerance intent |
| --- | --- | --- |
| Chamber volume | Workbook input and water-fill measurement | Tuning critical |
| Voicing window width/height | Workbook input | Playability critical |
| Windway gap | CAD/test-piece measurement | Playability critical |
| Labium angle and edge thickness | CAD/test-piece measurement | Playability critical |
| Wall thickness | Workbook input and cast measurement | Tone/drying critical |
| Hole diameters | Workbook chart and tuning log | Tuning critical |
| Master scale factor | Measured clay shrinkage | Process critical |

## Notes For CAD

- Store chamber volume as a named parameter.
- Store shrinkage factor as a named parameter.
- Separate final fired dimensions from master dimensions.
- Mark fipple geometry as prototype-sensitive; do not freeze it until test pieces speak reliably.
- Include a versioned body ID so castings can be tied back to the CAD master.

## assembly-manual.md

Shop-facing sequence, tools, fixtures, safety, tuning, finishing, and maintenance notes.

# Ocarina Assembly Manual

## Scope

This manual covers a slip-cast or press-molded ceramic ocarina based on `docs/Ocarina.xlsx`. It is written for prototype builds where the first goal is repeatable tone and validated tuning, not decorative finish.

## Tools

- CAD package for master design.
- 3D printer and sanding/sealing supplies.
- Cottle boards, plaster mixing bucket, scale, mold soap, and clamps.
- Stoneware slip or workable clay body.
- Small hole cutters, drill bits, needle tools, loop tools, ribs, sponge, and fettling knife.
- Chromatic tuner, microphone, calipers, graduated syringe or water-fill vessel.
- Diamond needle files or fine diamond burrs.
- Wax resist, glaze, and kiln access.

## Process

1. **Set design inputs**
   - Confirm target ocarina size, chamber volume, voicing window, wall thickness, clay body, and shrinkage.
   - Create a build ID before CAD begins.

2. **Model the master**
   - Model the body as a controlled-volume vessel.
   - Include split-line planning, registration features, and a fipple strategy.
   - Scale the master by `1/(1 - measured_shrinkage)`.

3. **Print and finish the master**
   - Print the master with enough wall strength to survive mold making.
   - Sand layer lines and seal the surface.
   - Mark datums: centerline, mouthpiece axis, split plane, and hole reference side.

4. **Make the mold**
   - Apply release to the sealed master and cottle surfaces.
   - Pour plaster with at least 1.5 inches around the master where practical.
   - Add registration keys and dry the mold fully before casting.

5. **Cast or press the body**
   - For slip casting, pour slip, wait for target wall buildup, drain, and demold at leather-hard stage.
   - For press molding, press even clay slabs into both mold halves and join with scored slip.
   - Measure sample wall thickness at a noncritical trimmed area.

6. **Cut fipple and holes**
   - Establish the windway first.
   - Cut the labium cleanly and test blow before the body fully dries.
   - Cut finger holes undersized.

7. **Dry slowly**
   - Dry under plastic until moisture equalizes.
   - Watch the mouthpiece and seam areas for cracks.

8. **Bisque fire**
   - Bisque to the clay body's recommended schedule.
   - Measure mass, volume, hole diameters, and frequencies.

9. **Tune after bisque**
   - Enlarge holes to raise pitch.
   - Refine the fipple only in small steps.
   - Record measured frequency and cents error after each change.

10. **Glaze**
    - Wax resist the windway, labium, holes, and any interior opening.
    - Keep glaze away from the acoustic edges.

11. **Final fire and validation**
    - Fire to the chosen glaze schedule.
    - Re-measure all tuning points.
    - Save final dimensions and tuning data back into the validation log.

## Failure Modes To Watch

- Weak or no tone: windway too tall, labium too blunt, air jet missing edge.
- Pitch too flat: chamber too large, open area too small, or neck length too long.
- Pitch too sharp: chamber too small, open area too large, or over-filed holes.
- Warped mouthpiece: uneven drying or thin unsupported fipple geometry.
- Glaze-choked note: glaze reduced hole or windway opening.

## validation.csv

Target/measured values, tolerance, environment, result, and tuning/build action log.

| build_id | stage | date | clay_body | shrinkage_expected_pct | master_scale_factor | chamber_volume_cm3 | wall_thickness_cm | voicing_w_cm | voicing_h_cm | hole_id | target_note | target_freq_hz | measured_freq_hz | cents_error | action | result | notes |
| --- | --- | --- | --- | --- | --- | --- | --- | --- | --- | --- | --- | --- | --- | --- | --- | --- | --- |
| OCA-P0 | voicing_tile |  |  |  |  |  |  |  |  | all_closed | A4 | 440 |  |  |  |  | Practice fipple before full body. |
| OCA-P1 | greenware |  |  |  |  | 130 | 0.4 | 0.9 | 0.5 | all_closed | A4 | 440 |  |  |  |  | Measure before drying if possible. |
| OCA-P1 | bisque |  |  |  |  | TBD | TBD | TBD | TBD | all_closed | A4 | 440 |  |  |  |  | First real model check. |
| OCA-P1 | glaze_fire |  |  |  |  | TBD | TBD | TBD | TBD | all_closed | A4 | 440 |  |  |  |  | Record glaze shift. |
| OCA-P2 | bisque |  |  |  |  | TBD | TBD | TBD | TBD | hole_1 | Bb4 | 466.2 |  |  |  |  | Start undersized and enlarge gradually. |
| OCA-P2 | bisque |  |  |  |  | TBD | TBD | TBD | TBD | hole_2 | B4 | 493.9 |  |  |  |  | Record hole diameter after tuning. |
| OCA-P2 | bisque |  |  |  |  | TBD | TBD | TBD | TBD | hole_3 | C5 | 523.3 |  |  |  |  | Check breath pressure sensitivity. |
| OCA-P3 | glaze_fire |  |  |  |  | TBD | TBD | TBD | TBD | hole_12 | A5 | 880 |  |  |  |  | Full 12-hole validation row. |

## supplier-rfq.md

Supplier email/request-for-quote starter.

# Supplier RFQ — Slip-Cast Ceramic Ocarina (OCA-001 family)

> Use this as a template for outreach to ceramic-supply, plaster, mold-making, and finishing suppliers. Customize the Subject and address fields per recipient.

**Subject:** RFQ — slip-cast ceramic ocarina prototype materials and consumables

Hello,

I'm a mechanical R&D engineer prototyping a small family of slip-cast ceramic ocarinas (vessel flutes, ~3-4 in long, ~0.16 in / 4 mm wall) and need quotes for the following. The first build is an Alto C 12-hole prototype based on the parametric Helmholtz design table at [tonykoop/ocarina](https://github.com/tonykoop/ocarina).

## Items

| # | Item | Required spec | Approx. qty (per prototype run) |
|---|---|---|---|
| 1 | Cone 6 stoneware casting slip | Mature Cone 6 stoneware slip with **published shrinkage** (X/Y/Z), **water absorption %**, and **firing schedule**. White or light buff body preferred for tone consistency over dark iron-bearing slips. | 1-5 gal |
| 2 | #1 pottery plaster | USG #1 Pottery Plaster (or equivalent) suitable for absorbent slip-cast molds. Need **water:plaster ratio**, **set time**, **soluble salt content**. | 10 lb (single mold) — 50 lb (production mold set) |
| 3 | Mold release / mold soap | Plaster-compatible parting agent (Murphy's-type oil soap or commercial mold soap). | 1 bottle / 16 oz |
| 4 | Cone 6 exterior glaze | Food-safe (or durable non-food-safe) satin or matte glaze. Color: TBD per family — likely earth/buff/cream. Glaze must not bridge holes or windway. | 3-5 pints |
| 5 | Brushable wax resist | Standard ceramic wax resist for masking voicing window, finger holes, and chamber interior pre-glaze. | 1 small jar / 8 oz |
| 6 | Diamond needle file set (post-bisque tuning) | Assorted profiles (round, half-round, taper) ~3-6 mm; resin-bonded acceptable. | 1 set |
| 7 | Hole cutters / brass tube cutters | Round cutters from ~0.156 in (4 mm) to ~0.313 in (8 mm) diameter for greenware finger-hole cutting. | 1 set |
| 8 | Bisque + glaze firing service (if local) | Cone 06 bisque + Cone 6 glaze fire; small cubic-foot kiln load. | 2 fires per prototype |
| 9 | (Optional) Master printing/outsource | If you do high-resolution PLA or resin prints up to ~5 in long with **0.005 in dimensional accuracy**, please quote. We currently print in-house but want a backup. | 1-5 master pairs |

## What we need in your quote

- **Unit price** and any volume breaks
- **Minimum order quantity**
- **Current stock status** and **lead time**
- **Shipping estimate** to 94566 (Pleasanton, CA) — or local pickup option
- **Material safety data sheet (MSDS)** and **technical data sheet** for items 1, 2, 4, 5
- **Recommended substitutions** for thin-walled (~4 mm) musical instrument bodies
- For item 1: most recent **shrinkage test data** for your batch (we will re-measure on our side, but a baseline matters)

## Acceptance criteria

The prototypes are measured for X/Y/Z shrinkage, bore/cavity volume after firing, wall-thickness consistency, and acoustic tuning (chromatic tuner, ±25 cents target post-bisque). Slip with unknown or wildly variable shrinkage invalidates the master scale factor (currently `1/(1-0.12) = 1.136`), so reproducibility data is more valuable than headline price.

The repo is a private R&D portfolio repo; we do not need any IP-restricted documents. Public-domain MSDS and supplier spec sheets are sufficient.

Thank you,

Tony Koop
Mechanical R&D Engineer
tonykoop@gmail.com
github.com/tonykoop/ocarina (private; access on request)

## visual-bom-brief.md

Art direction for an image-forward visual BOM.

# Ocarina Visual BOM Brief

## Goal

Create a one-page visual BOM that helps a builder understand the ceramic ocarina workflow from digital master to tuned fired instrument.

## Layout

- Header: "Slip-Cast Ceramic Ocarina - Alto C Prototype".
- Hero image: finished ocarina or clean CAD render.
- Process strip: CAD master, 3D print, plaster mold, greenware, bisque, tuning, glaze fire.
- BOM table: item number, part/material, quantity, spec, estimated cost, make/buy, image.
- Callout inset: fipple section with windway, labium, and voicing window labels.
- Validation inset: chamber volume, all-closed note, highest tested note, cents error.

## Image Requirements

Use real shop photos when available. Generated or rendered placeholders should be labeled as placeholders until replaced with:

- Master print photo.
- Plaster mold photo.
- Greenware body photo.
- Fipple close-up.
- Final fired instrument.
- Tuning tool/photo of measurement setup.

## wolfram-starter.wl

Wolfram starter for physics, optimization, visualization, and validation.

```wolfram
(* Ocarina Helmholtz notebook starter *)

ClearAll["Global`*"];

c = 34300; (* cm/s at about 20 C *)
targetA4 = 440;
volumeCm3 = 130;
wallCm = 0.4;
windowWcm = 0.9;
windowHcm = 0.5;

voicingAreaCm2[w_, h_] := w*h;
endCorrectionCm[area_] := 0.6*Sqrt[area/Pi];
helmholtzHz[area_, volume_, neckLength_] :=
  (c/(2*Pi))*Sqrt[area/(volume*neckLength)];
centsError[measured_, target_] := 1200*Log[2, measured/target];

baseArea = voicingAreaCm2[windowWcm, windowHcm];
baseNeck = wallCm + endCorrectionCm[baseArea];
baseFreq = helmholtzHz[baseArea, volumeCm3, baseNeck];

holeDiameterMmToAreaCm2[d_] := Pi*(d/20)^2;
targetFreq[midi_] := 440*2^((midi - 69)/12);
areaForFrequency[f_, volume_, neckLength_] :=
  volume*neckLength*(2*Pi*f/c)^2;

(* Candidate cumulative area table for A4 to A5. *)
notes = {
  {"A4", 69}, {"Bb4", 70}, {"B4", 71}, {"C5", 72},
  {"C#5", 73}, {"D5", 74}, {"D#5", 75}, {"E5", 76},
  {"F5", 77}, {"F#5", 78}, {"G5", 79}, {"G#5", 80}, {"A5", 81}
};

areaTable = Table[
  With[{freq = targetFreq[midi]},
    {name, freq, areaForFrequency[freq, volumeCm3, baseNeck]}
  ],
  { {name, midi}, notes}
];

areaTable // TableForm
```

## README.md

Project artifact.

# Ocarina — Slip-Cast Ceramic Vessel-Flute Family

> *Engineering documentation for a 3D-printed-master, plaster-mold, cone-6-stoneware slip-cast ocarina family — from Helmholtz physics through the parametric design table to a manufacturable build packet.*

Hero — AI-generated concept render of a slip-cast Alto C 12-hole ocarina (placeholder until first prototype is photographed)
*AI-generated concept render — replace with photo of first OCA-P1 prototype after firing. Manufacturing dimensions come from the parametric design table, not from this image.*

## What this is

Engineering documentation for a small family of slip-cast ceramic ocarinas, built around the Helmholtz vessel-resonator model and a 3D-printed-master / plaster-mold / Cone-6-stoneware production pipeline. The repository combines:

1. **A parametric design table** ([`ocarina-design-table.xlsx`](ocarina-design-table.xlsx)) — chamber volume, voicing-window geometry, wall thickness, shrinkage, and a 12-hole fingering chart with formula-driven hole-area / cumulative-area / frequency columns. Master scale factor `1/(1 - measured_shrinkage)` is parameterized; for a 12% shrinkage assumption, the master scales at ~1.136×.
2. **A full build packet** ([`design.md`](design.md), [`bom.csv`](bom.csv), [`sourcing.csv`](sourcing.csv), [`cut-list.csv`](cut-list.csv), [`validation.csv`](validation.csv), [`assembly-manual.md`](assembly-manual.md), [`supplier-rfq.md`](supplier-rfq.md), [`drawing-brief.md`](drawing-brief.md), [`visual-bom-brief.md`](visual-bom-brief.md), [`wolfram-starter.wl`](wolfram-starter.wl)) — the same scaffold used across the [`tonykoop`](https://github.com/tonykoop) musical-instrument catalogue.
3. **A capstone slide deck and printable shop packet** ([`capstone-deck.pptx`](capstone-deck.pptx), [`print-packet.pdf`](print-packet.pdf)) — recruiter-facing artifacts that show the design is documented well enough that someone else could build it.

Sister repos: [`gemshorn`](https://github.com/tonykoop/gemshorn) (where slip-cast horn-flute mold workflow was established and is the closest comparable build packet), [`transverse-flute`](https://github.com/tonykoop/transverse-flute) (slip-cast workflow at larger scale), [`flutes`](https://github.com/tonykoop/flutes) (the NAF / open-pipe family with empirical K2 bore corrections), and [`instrument-maker`](https://github.com/tonykoop/instrument-maker) (the agent skill that generated this packet).

## Background — what makes an ocarina different

The ocarina (Italian *little goose*) is a closed-cavity vessel flute. Unlike a transverse flute or a Native American style flute, **pitch is set by chamber volume and total open-hole area, not by tone-hole position along a bore**. The governing model is the Helmholtz resonator:

```
f = c/(2π) · √( A_open / (V_chamber · L_eff) )
```

where `A_open` is the cumulative open hole area, `V_chamber` is the closed cavity volume, and `L_eff = wall_thickness + 0.6·√(A_open/π)` is the effective neck length with a flanged-port end correction. The full physics treatment is in [`design.md`](design.md) (Governing Model section) and in [`wolfram-starter.wl`](wolfram-starter.wl).

The practical consequence is that ocarina hole positions are an **ergonomic** problem (where the fingers reach), not an acoustic one (where the standing wave wants the holes). This makes the ocarina an unusually clean parametric-design target — change the chamber volume, the whole register transposes; change the cumulative area, the fingering chart re-tunes — but it puts an unusually heavy burden on **fipple/voicing geometry**, which the Helmholtz model says nothing about and which has to be tuned empirically.

## Family targets

The first prototype is the magazine-standard **Alto C 12-hole** (target low note A4 = 440 Hz, target high note F6 ≈ 1397 Hz, chamber volume 130 cm³ per the design table). The same parametric model can drive a Soprano C / Bass C extension once the Alto C voicing geometry is stable — see the prototype ladder in [`design.md`](design.md).

| Prototype | Goal | Success criteria |
|---|---|---|
| **OCA-P0** voicing tile | Fipple-only practice cavity | Clear tone on a disposable test cavity |
| **OCA-P1** closed vessel | Verify chamber volume + fipple | Stable A4-ish all-closed tone before holes |
| **OCA-P2** 4-hole | Prove tuning workflow | Four tuned notes within ±25 ¢ post-bisque |
| **OCA-P3** 12-hole | Full range | Chromatic A4–A5 playable, no blocked grip |
| **OCA-P4** matched set | Soprano / Alto / Bass C | Shared mold logic, shared glaze family |

## Hardware alignment — Bambu printer + ceramic kiln

This repo is one of the **slip-casting targets** for the in-flight Bambu printer + kiln pipeline. The build chain is:

1. Parametric design table sets fired-body dimensions.
2. Master scale factor `1/(1 - measured_shrinkage)` scales the master STL.
3. Bambu print masters in PLA (or sealable resin); sand layer lines and seal.
4. Two-piece plaster mother mold around the sealed master.
5. Slip-cast Cone 6 stoneware → demold leather-hard → cut voicing window and finger holes undersized → bisque → tune → glaze → final fire.
6. Validate against [`validation.csv`](validation.csv); fold corrections back into the design table.

The same pipeline serves the [`udu`](https://github.com/tonykoop/udu), [`gemshorn`](https://github.com/tonykoop/gemshorn), and [`transverse-flute`](https://github.com/tonykoop/transverse-flute) repos.

## Repository structure

```
ocarina/
├── README.md                       ← you are here
├── LICENSE                         ← CC-BY 4.0
│
├── design.md                       ← Helmholtz model, design intent, prototype ladder
├── ocarina-design-table.xlsx       ← parametric spreadsheet (formulas, blue inputs)
│
├── bom.csv                         ← bill of materials
├── sourcing.csv                    ← supplier/search tracker
├── cut-list.csv                    ← rough/finished dimensions, tolerances
├── validation.csv                  ← target/measured tuning + cents-error log
├── supplier-rfq.md                 ← RFQ template for slip / plaster / consumables
│
├── assembly-manual.md              ← shop-floor build sequence
├── drawing-brief.md                ← required views + critical dimensions for CAD
├── visual-bom-brief.md             ← visual-BOM art-direction brief
├── wolfram-starter.wl              ← Helmholtz physics starter notebook
│
├── capstone-deck.{md,pptx}         ← capstone slide deck (12 slides)
├── print-packet.{md,html,pdf}      ← combined print-ready shop packet (18 pp)
├── capstone-manifest.json          ← orientation manifest
│
├── cad/                            ← parametric body OpenSCAD starter
├── cnc/                            ← (deferred — slip-cast does not need CNC unless turning a wooden master)
├── drawings/                       ← SVG drawings: section, fipple detail, hole layout
└── images/                         ← AI-generated concept renders (placeholders)
```

## Status

| Section | Status |
|---|---|
| Parametric design table + Helmholtz model | ✓ done |
| Build packet (BOM / sourcing / cut-list / validation / RFQ) | ✓ done |
| Assembly manual + drawing brief | ✓ done |
| Wolfram physics starter | ✓ done |
| Capstone deck + print packet | ✓ done (auto-generated, recruiter-facing) |
| Concept renders (AI-generated, captioned) | ✓ done (placeholders) |
| Parametric CAD (OpenSCAD starter) | ✓ done (master-shape only; voicing detail by hand) |
| Dimensioned drawings (SVG) | ✓ done (section + hole layout) |
| Production-ready CAD (.step / .stl) | **deferred** — generated after empirical voicing validation in build queue |
| Mold turning / CNC toolpaths | **deferred** — slip-cast workflow uses 3D-printed master, not turned wooden master |
| First OCA-P1 prototype build | forthcoming (Bambu + kiln pipeline) |

Tier 3 production files (.step, validated .stl, .dxf for laser, .gcode for CNC) are **out of scope until the first OCA-P1 prototype validates voicing geometry**. See the README's status table and [`design.md`](design.md) "Open Assumptions" for the deferral reasoning.

## License

Released under [CC-BY 4.0](LICENSE) — original written content, design files, photographs, and physics work in this repository are mine, free to reuse and adapt with credit.

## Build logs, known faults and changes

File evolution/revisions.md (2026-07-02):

# Revision Register — ocarina

| Rev | Date | Parent | Delta | Downstream artifacts invalidated |
| --- | --- | --- | --- | --- |
| A | 2026-07-01 | — | Stage 0 intake of current masters (cad/ocarina_master.scad + ocarina-design-table.xlsx). | none (no alpha/beta/production artifacts exist yet) |

Stage 0 only. Gate A has not been run; no Alpha compiles, vendor quotes, or production lock exist for this product.

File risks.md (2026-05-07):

# Risks

This file was scaffolded by `migrate_packet.py` during the v3 → v4 upgrade.
Run `red-team` specialist or fill in by hand.

## Acoustic

(none identified — replace with real risks before shipping)

## Structural

(none identified — replace with real risks before shipping)

## Ergonomic

(none identified — replace with real risks before shipping)

## Supply

(none identified — replace with real risks before shipping)

## Fit/Finish

(none identified — replace with real risks before shipping)

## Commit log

2026-05-02 Scaffold: LICENSE, .gitignore, design table, README
    [ocarina-design-table.xlsx]
2026-05-02 Migrate build packet from instrument-maker/docs/build-packets/ocarina
    [bom.csv, sourcing.csv, validation.csv]
2026-05-02 Generate full build packet via instrument-maker [v2]
    Tier 1: cut-list, supplier-rfq, capstone-deck (md+pptx, 12 slides),
    print-packet (md+html+pdf, 51 pp), capstone-manifest, README rewrite.
    Tier 2: cad/ocarina_master.scad (parametric Helmholtz vessel),
    drawings/ (3 SVGs: body section, 12-hole layout, mold schematic),
    images/ (3 AI-generated concept renders).
    Tier 3 (.step/.stl/.dxf) deferred until OCA-P1 voicing validation.
    Skill: skills/v2/instrument-maker-v2/SKILL.md
    Tracking issue: tonykoop/instrument-maker#55
    [cut-list.csv, ocarina_master.scad]
2026-05-18 Add V5 explorer authority ledgers (#3)
    [family-spec.csv, validation-loop.csv, visual-output-register.csv]
2026-05-31 Add image-gen concept prompt; wire explorer images
2026-06-21 Wire 3 rendered concept image(s) into explorer gallery
2026-07-02 V5 packet refresh: status line, evolution intake
    Added parseable **Status:** L2 V5 build-packet candidate line (kept prose status
    table + narrative). Stage 0 evolution intake (master manifest, design-intent,
    revisions). Existing cad/ocarina_master.scad kept (no rewrite); openscad render
    check pass. mcp-session-log + register already present.
    Foreign uncommitted change to visual-output-register.csv (IMG-004 concept-image
    row) left untouched — not part of this refresh.
    v5-validator: 1 fail -> 0 fails.
2026-07-02 feat(arena): Code-CAD Arena Round 1 winning model (generated, not a master)
    Winning blind-vote candidate from makerbench-hwe Code-CAD Arena round1,
    exported by 'makerbench arena export-winners'. See arena/round1/provenance.json
    for entrant, votes, and gate sub-scores. AI-generated artifact - never a
    measured master or validated build packet.
    Claude-Session: https://claude.ai/code/session_01Ew72pzuM36NwvCSbcruyxs
    [ocarina-arena-winner.scad, ocarina-arena-winner.stl]
